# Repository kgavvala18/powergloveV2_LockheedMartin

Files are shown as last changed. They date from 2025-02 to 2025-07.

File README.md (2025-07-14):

# PowergloveV2 - Sponsored by Lockheed Martin

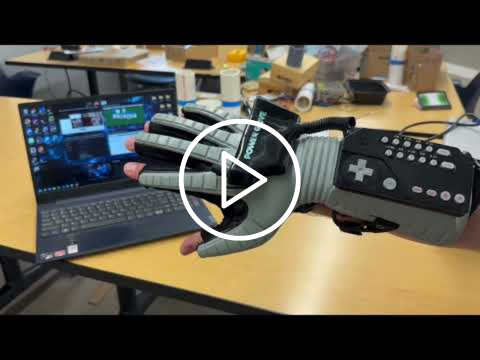
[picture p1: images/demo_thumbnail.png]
Watch the video (https://youtu.be/ArDcWYFsmJc)
||
|:--:|
| watch demo on youtube: https://www.youtube.com/watch?v=ArDcWYFsmJc|

The reimagined Power Glove enhances human-computer interaction by introducing a touchless interface that translates intuitive hand gestures into precise digital input. Designed to replace the traditional mouse, it enables seamless control through natural motion, offering a more ergonomic, immersive, and futuristic method of interaction. Users can simply connect the glove to their computer via Bluetooth and control it using hand movements. The glove tracks hand motion to move the cursor and detects gestures to trigger commands such as click, zoom, scroll, and more.

The system integrates an accelerometer/gyroscope IMU to track hand movement and orientation on three axes. Flex sensors embedded in each finger detect varying degrees of flexion, which, when combined with motion and orientation data, enable functions such as clicking, dragging, zooming, scrolling, and activating a laser pointer. Additional buttons on the glove provide quick access to common keyboard shortcuts like Ctrl+C and Ctrl+V. The Adafruit Feather nrf52840 Sense microcontroller was used for its processing speed, bluetooth LE, and usb charging capabilities.

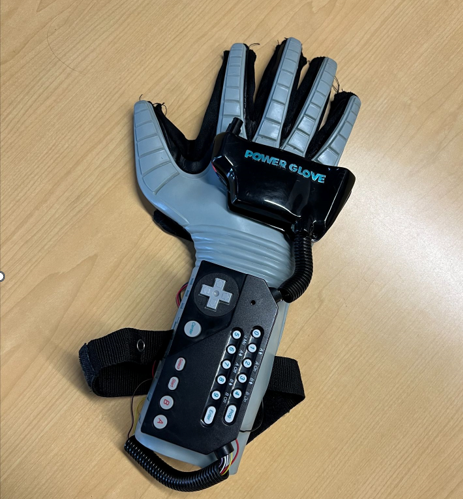
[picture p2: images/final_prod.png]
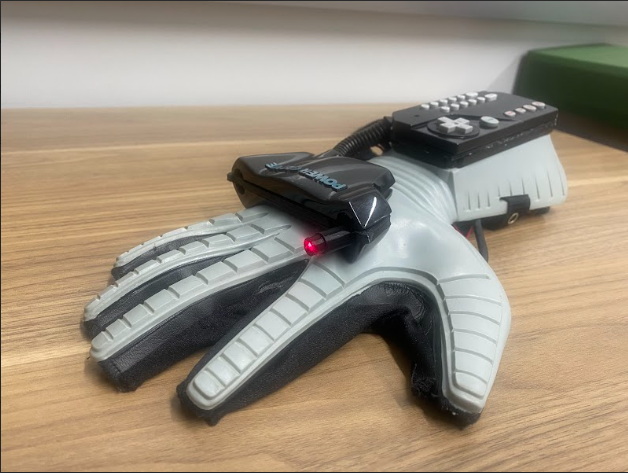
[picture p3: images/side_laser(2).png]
||
|:--:|:--:|

# Design 

Parts:

- [Adafruit feather nrf52840 sense](https://learn.adafruit.com/adafruit-feather-sense/overview)
- [LSMD6SOX IMU](https://learn.adafruit.com/lsm6dsox-and-ism330dhc-6-dof-imu/overview)
- 5x Flex sensors 
- Buttons 
- USB-C charging port
- Rechargeable 3.7 V LiPo battery
- 5x 400k ohm resistors
- 2n7000 mosfet transistor
- 10 uf capacitor
- 650 nm  5 mW laser

Layout: 

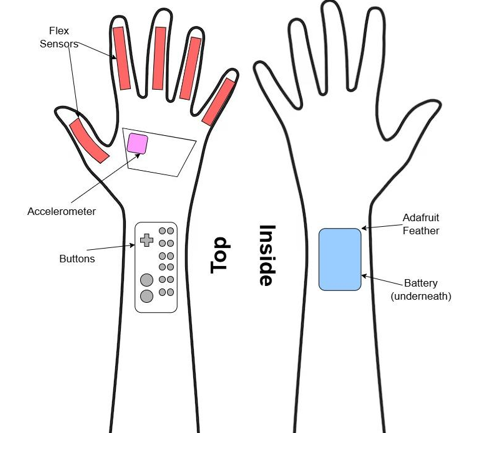
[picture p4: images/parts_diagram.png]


Level Diagram:

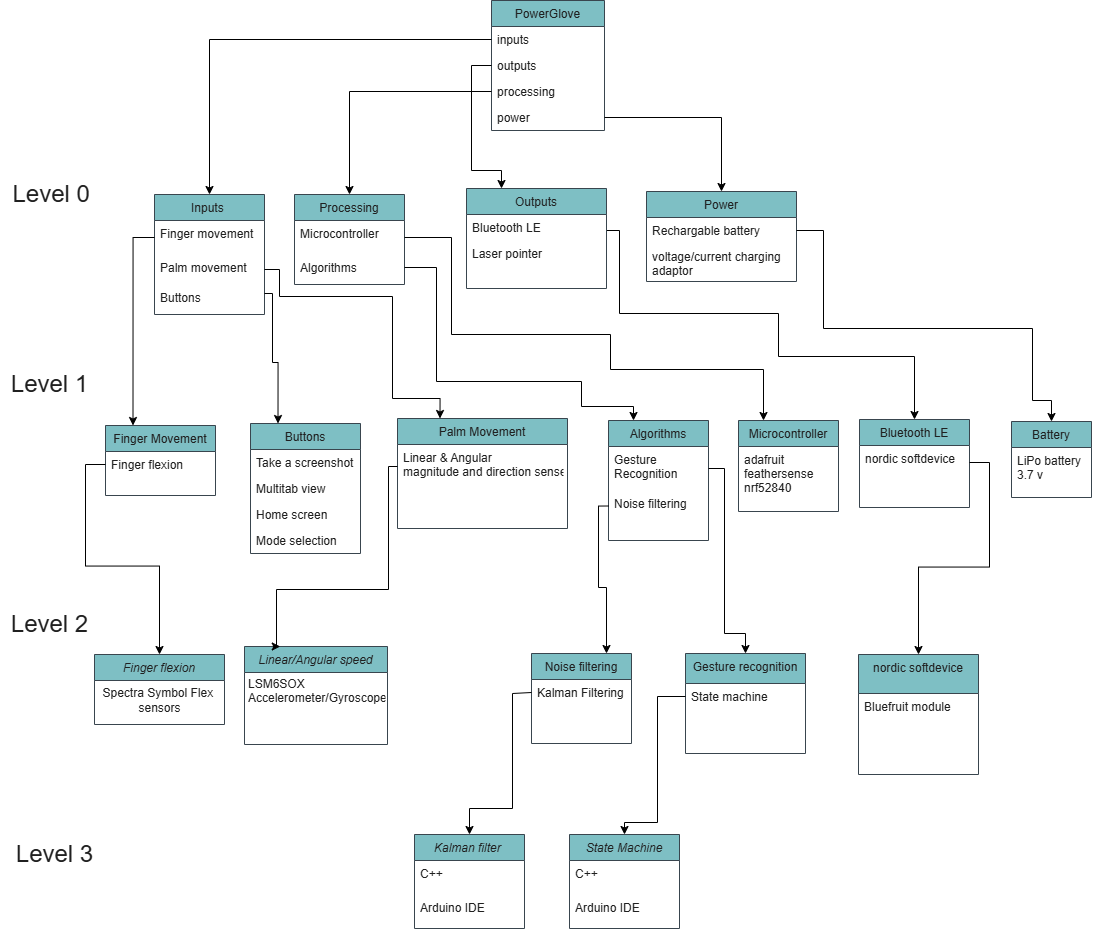
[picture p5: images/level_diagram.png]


# Project google drive folder
https://drive.google.com/drive/folders/1QBTlvf5KhOVl-Dzjxu-7hFhMazjApdm0?usp=sharing

# For Windows and Linux

1. Download Arduino IDE at https://www.arduino.cc/en/Main/Software
2. Start Arduino IDE and go to preference and add https://adafruit.github.io/arduino-board-index/package_adafruit_index.json as an 'Additional Board Manager URL'
3. Restart the IDE
4. Open Board Manager in the Tools -> Board and install 'Adafruit nRF52 by Adafruit'
5. After install use Tools -> Board to select Adafruit Feather nRF52840 Sense 

# For Windows Only

Windows Users will likely need to install the following two links
Select all options when installing below
https://learn.adafruit.com/adafruit-arduino-ide-setup/windows-driver-installation
CP210x Windows Drivers option is what I had to choose
https://www.silabs.com/developer-tools/usb-to-uart-bridge-vcp-drivers?tab=downloads

# For Linux Only 

Follow above windows steps and then follow below if python3 is not installed already

Linux Users will likely need to install https://www.silabs.com/developer-tools/usb-to-uart-bridge-vcp-drivers

1. Run `$ sudo apt-get install python3`
2. Run `$ pip3 install --user adafruit-nrfutil`
3. Add to path if needed
4. Ensure adafruit-nrfutil can be executed in terminal by running `$ adafruit-nrfutil version`

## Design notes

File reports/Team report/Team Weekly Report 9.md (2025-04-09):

**Team Weekly Report 9**

**Team:** The Gauntlet  
**Week:** 9  
**Members:** Kris Gavvala, [David Johnson](mailto:bluetech314@tamu.edu), [Aaron Martinez](mailto:aaron33@tamu.edu),  [Brint Nielson](mailto:brintcnielson@tamu.edu), [Will Tatum](mailto:willtaaa@tamu.edu), [Grant Turner](mailto:grantt731@tamu.edu)

| Status Report |
| :---- |

*Write a one-third to one-half page status report describing the team’s overall progress and challenges faced last week. Also discuss the team’s goals and plan for this week.*

The team has made good progress last week. The buttons have been assembled and the sensors have all been soldered in. The glove has now been mostly assembled with the main goal now being to make it pretty.
The team faced some challenged with fitting all of the sensors and wires within the enclosure and have been working on getting 3D printed pieces to remedy this.
The goals for this coming week are to finish assembling the glove and getting everything secured, finish integrating the gestures and buttons into the codebase, get the zoom functionality working, and if time permits, work on the drivers.

| Current Status |
| :---- |

1. What did the team work on this past week?

| Task | Task Lead | Status | Notes |
| :---- | :---- | :---- | :---- |
| Remade the buttons | Grant | Complete | No notes |
| Coding and assembly | Kris | Ongoing | Filtered flex sensors and assembled laser diode & glove |
| 3D printing | Brint | Ongoing | Need to test to develop and integrate |
| Bluetooth optimizations | Will | Complete | No notes |
| Soldering and assembly | Aaron | Ongoing | Got glove soldered with all of the sensors |
| Event code for buttons | David | Complete | Have not been able to test yet |

2. What feedback has the team received?

| From Whom | Feedback | Next Steps |
| :---- | :---- | :---- |
| Ritchey | Get predefined gestures working and assignable | Detect different gestures |
|  |  |  |

3. Are any resources needed? If so, what?

No

| Plans for Next Week |
| :---- |

What are your plans for this next week?

| Task | Task Lead | Notes |
| :---- | :---- | :---- |
| 3D Printing | Brint | Enclosure for laser and spacer |
| Integrate gestures and events into codebase | David | Will be done after testing |
| Drivers | Will | This is a stretch goal |
| Assembling the glove | Aaron | Continuation of glove assembly |
| Code the buttons | Grant | Build on event test code |
| Work on getting zoom working | Kris | Might be buttons or gesture |

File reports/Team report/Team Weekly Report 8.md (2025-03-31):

**Team Weekly Report 8**

**Team:** The Gauntlet  
**Week:** 8  
**Members:** Kris Gavvala, [David Johnson](mailto:bluetech314@tamu.edu), [Aaron Martinez](mailto:aaron33@tamu.edu),  [Brint Nielson](mailto:brintcnielson@tamu.edu), [Will Tatum](mailto:willtaaa@tamu.edu), [Grant Turner](mailto:grantt731@tamu.edu)

| Status Report |
| :---- |

*Write a one-third to one-half page status report describing the team’s overall progress and challenges faced last week. Also discuss the team’s goals and plan for this week.*

Last week, our group wrapped up all the individual components for the glove and it is partially assembled. We did have an issue with several members being ill which delayed our progress.   
The team will be finishing the glove’s assembly and will be moving on to getting the drivers. The next steps will be finishing the drivers, integrating them into the GUI, and getting all of the software and events onto the glove. We now have a prototype of the 3D printed spacer and will be getting a finalized version quickly.

| Current Status |
| :---- |

1. What did the team work on this past week?

| Task | Task Lead | Status | Notes |
| :---- | :---- | :---- | :---- |
| We set up the button encoder. | Grant | Complete |  |
| The Events are set up | David | Complete | Copy paste was dropped due to strange difficulties |
| Drivers | Brint | Ongoing | Need to test to develop and integrate |
| GUI | Will | Ongoing | Drivers are a prerequisite to ensuring GUI works |
| 3D print casings | Brint | Ongoing | Got good base prints down now need to adjust to fit the height as well |

2. What feedback has the team received?

| From Whom | Feedback | Next Steps |
| :---- | :---- | :---- |
|  |  |  |
|  |  |  |

3. Are any resources needed? If so, what?

Power switch.

| Plans for Next Week |
| :---- |

What are your plans for this next week?

| Task | Task Lead | Notes |
| :---- | :---- | :---- |
| Drivers | Brint |  |
| 3d Print  | Brint |  |
| GUI | Will |  |
| Assembling the glove | Aaron/Grant/Kris |  |
| Transferring events to glove | David |  |
| Finish flex sensors | Aaron/Grant/Kris |  |

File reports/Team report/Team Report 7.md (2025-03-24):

# Team Weekly Report

**Team**: The Gauntlet

**Week**: 7

**Members**: David, Grant, Brint, Kris, Aaron, Will

## Status Report

The team's overall progress is good. The glove is coming together swiftly and although we have had some setbacks from members being sick, progress has been good.
There has been work on hooking up the buttons to the encoders, getting everything soldered for the status demo, and some more mouse movement along with some gestures.
We have made progress on the 3D printing side but are having difficulties with the strange geometry of the parts we are trying to print for. The GUI has made progress
but now it needs some drivers to connect the keybinds to the glove and be able to light up a hand SVG properly. The drivers have been difficult to do because none of our
members have experience working on Windows drivers.

## Current Status
The glove is coming along very well and we have a working prototype. We are working on getting the housing, the buttons, the drivers, and the GUI to work.

### What did the team work on this past week?

| Task | Task Lead | Status | Notes |
| ---- | --- | --- | ----- |
| GUI | Will | In Progress | Needs the drivers to continue |
| Soldering | Aaron | Complete | Will need to be changed again |
| Buttons | Grant | In Progress | Hooked up to the encoders |
| Mouse Movement Code | Kris | In Progress | Need to experiment with deadzones |
| 3D Printing | Brint | In Progress | Hard to measure irregular surfaces accurately |
| Gestures | David | In Progress | Needs drivers to finish |

### What feedback has the team receieved?

| From Whom | Feedback | Next Steps |
| --- | --- | --- |
| Ritchey | Need clear demo (would like the GUI lightup thing) | Get the drivers working + SVG |
| Trevor | Try to ensure form factor with 3D printing | Keep our solutions minimally invasive to form factor |
| | | |

### Are any resources needed? If so, what?
We need a new charger piece and may need a new bluetooth module.

## Plans for Next Week

| Task | Task Lead | Notes |
| ---- | --- | ----- |
| Finish the buttons | Grant | They are hooked up to the encoders and are being put in the glove soon |
| Finish the cursor | Kris | Experimenting with deadzones and some other techniques |
| Finish the gestures | David | Gestures are coming along decently but need more precision |
| Finish the drivers | Will/Brint | Windows drivers are a new experience and are taking some time |
| Finish the 3D printing | Brint | 3D printing is facing some challenges with the geometry |
| Finish putting glove together | Aaron | Ordered more flex sensors since one of them is bending |

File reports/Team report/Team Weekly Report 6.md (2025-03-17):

**Team Weekly Report 6**

**Team:** The Gauntlet  
**Week:** 6  
**Members:** Kris Gavvala, [David Johnson](mailto:bluetech314@tamu.edu), [Aaron Martinez](mailto:aaron33@tamu.edu),  [Brint Nielson](mailto:brintcnielson@tamu.edu), [Will Tatum](mailto:willtaaa@tamu.edu), [Grant Turner](mailto:grantt731@tamu.edu)

| Status Report |
| :---- |

The overall progress is that the glove is nearing a functional prototype. The assembly work is underway and will be completed soon along with having some gestures set up. The GUI is also being developed and will be finished in time. The translation code and the button encoder were both completed and are ready for the next steps. The development environment for the drivers has been set up and the parts are being designed for 3D printing. The challenges faced last week included the error from the magnetometer. The team had to purchase a better one to reduce the errors after integrating it.  
Our goal for this week is to assemble the glove to have a prototype that we can test. We want to integrate all of the separate pieces onto the glove such as the flex sensors, controller, and buttons. While this occurs, some team members will continue software development, making drivers, the GUI, and new events.

| Current Status |
| :---- |

1. What did the team work on this past week?

| Task | Task Lead | Status | Notes |
| :---- | :---- | :---- | :---- |
| We set up the button encoder. | Grant | Complete |  |
| Translation code | Brint/Will | Complete | Sometimes loses track of the mouse, may incorporate a magnetometer for a reference |
| Drivers | Brint | Ongoing | Environment setup |
| GUI | Will | Ongoing | Technically started last weekend over spring break |

2. What feedback has the team received?

| From Whom | Feedback | Next Steps |
| :---- | :---- | :---- |
| Ritchey | Would like a GUI that lights up based on what you press | Work has started on this |
| Trevor | Would like the buttons to open apps | Thinking about how to incorporate this |

3. Are any resources needed? If so, what?

Polo Shirts?

| Plans for Next Week |
| :---- |

What are your plans for this next week?

| Task | Task Lead | Notes |
| :---- | :---- | :---- |
| Drivers | Brint |  |
| GUI | Will |  |
| Assembling the glove | Aaron/Grant/Kris |  |
| Developing more Events | David |  |
| Finish flex sensors | Aaron/Grant/Kris |  |

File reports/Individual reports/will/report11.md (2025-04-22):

# Individual Weekly Report

**Name**: Will Tatum

**Team**: The Gauntlet

**Date**: 04/21/2025

## Current Status
The glove is nearly done now and just needs to be touched up on the outside.

### What did _you_ work on this past week?

| Task | Status | Time Spent | 
| ---- | --- | --- |
| Gesture Detection | Complete | 8 hr |
| Report/Poster | Complete | 2 hr |
| | | |

*Include screenshots/diagrams/figures/etc. to illustrate what you did this past week.*
  previousGesture = currentGesture;
  currentGesture = gesture(thumbFiltered, indexFiltered, middleFiltered, ringFiltered, pinkyFiltered);
  Serial.println(currentGesture);

  switch (gestureState)
  {
  case IDLE:
    if (currentGesture == DRAG_GESTURE)
    {
      blehid.mouseButtonPress(MOUSE_BUTTON_LEFT);
      gestureState = DRAG_EVENT;
    }
### What problems did you run into? What is your plan for them?

We ran into problems with the glove's wires coming out. We have solved this issue.

### What is the current overall project status from your perspective? 

I would say that the project is about 99% done.

### How is your team functioning from your perspective?

The team is functioning well and we have minimal issues. We got a lot done this last week and are on track.

### What new ideas did you have or skills did you develop this week?

We figured out how to get the gesture detection working as well as we could with this hardware.

### Who was your most awesome team member this week and why?

Grant is my most awesome team member this week since he did all of the button code and got it working.

## Plans for Next Week

*What are you going to work on this week?*

I am going to work on the poster and report to help get it finalized along with some tests and user studies.

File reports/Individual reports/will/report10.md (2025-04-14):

# Individual Weekly Report

**Name**: Will Tatum

**Team**: The Gauntlet

**Date**: 04/14/2025

## Current Status
The glove is nearly done now and just needs a little more refinement on the gesture detection and the casing.

### What did _you_ work on this past week?

| Task | Status | Time Spent | 
| ---- | --- | --- |
| Gesture Detection | In Progress | 8hr |
| | | |
| | | |

*Include screenshots/diagrams/figures/etc. to illustrate what you did this past week.*
  // left mouse button
  switch (leftState)
  {
  case MOUSE_IDLE:
    // At idle, check if we have a new left-click or drag gesture.
    if (gesture_ == R) // should be I
    {
      // Initiate a discrete left-click event.
      // (According to our grammar, a click is I followed by NONE.)
      blehid.mouseButtonPress(MOUSE_BUTTON_LEFT);
      leftState = CLICK_EVENT;
      mouseEnabled = false;
    }

### What problems did you run into? What is your plan for them?

We ran into problems with the gesture detection having conflicts with itself. The plan is to basically wait until the new gesture has stabilized before switching to it.

### What is the current overall project status from your perspective? 

I would say that the project is about 90% done.

### How is your team functioning from your perspective?

The team is functioning well and we have minimal issues. We got a lot done this last week and are on track.

### What new ideas did you have or skills did you develop this week?

We had ideas on using the mean and stdev of the sensors to detect if they are stabilized or not. Another idea was a stabilization window for the gestures.

### Who was your most awesome team member this week and why?

Kris is my most awesome teammate this week because he spent a lot of time getting everything working.

## Plans for Next Week

*What are you going to work on this week?*

I am going to continue working on gesture detection.

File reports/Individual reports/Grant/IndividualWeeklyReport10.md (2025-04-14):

# Individual Weekly Report

**Name**: Grant Turner

**Team**: The Gauntlet

**Date**: 4/14/2025

## Current Status

### What did _you_ work on this past week?

| Task | Status | Time Spent |
| --- | --- | --- |
| Started adding the code for buttons | In progress | 5hr |

_Include screenshots/diagrams/figures/etc. to illustrate what you did this past week._

### What problems did you run into? What is your plan for them?

When I first wrote the code to check which button was being pressed, the matchButton function caused a lot of lag with the mouse movement due to running a nested loop every iteration. To fix this I added a check at the beginning of the function to check if the inputs match no button being pressed which greatly increased speed.

### What is the current overall project status from your perspective?

The project is about 85-90% done at this point. We have mostly every intended feature implemented just need to continue to refine them to improve usability.

### How is your team functioning from your perspective?

The team is still functioning pretty well and mostly everyone is pulling their weight.

### What new ideas did you have or skills did you develop this week?

I worked on writing more Arduino code and focused on writing optimized algorithms to avoid largely slowing down the main loop in our code.

### Who was your most awesome team member this week and why?

Will was the most awesome teammate as he easily fixed our issue with clicking while moving the mouse.

## Plans for Next Week

Completely finish the glove and get our presentations fully prepared.
_What are you going to work on this week?_
Finish the buttons completely and help with other code.

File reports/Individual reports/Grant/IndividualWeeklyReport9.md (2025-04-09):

# Individual Weekly Report

**Name**: Grant Turner

**Team**: The Gauntlet

**Date**: 3/31/2025

## Current Status

### What did _you_ work on this past week?

| Task | Status | Time Spent |
| --- | --- | --- |
| Install buttons into board | In Progress | 3hr |

_Include screenshots/diagrams/figures/etc. to illustrate what you did this past week._

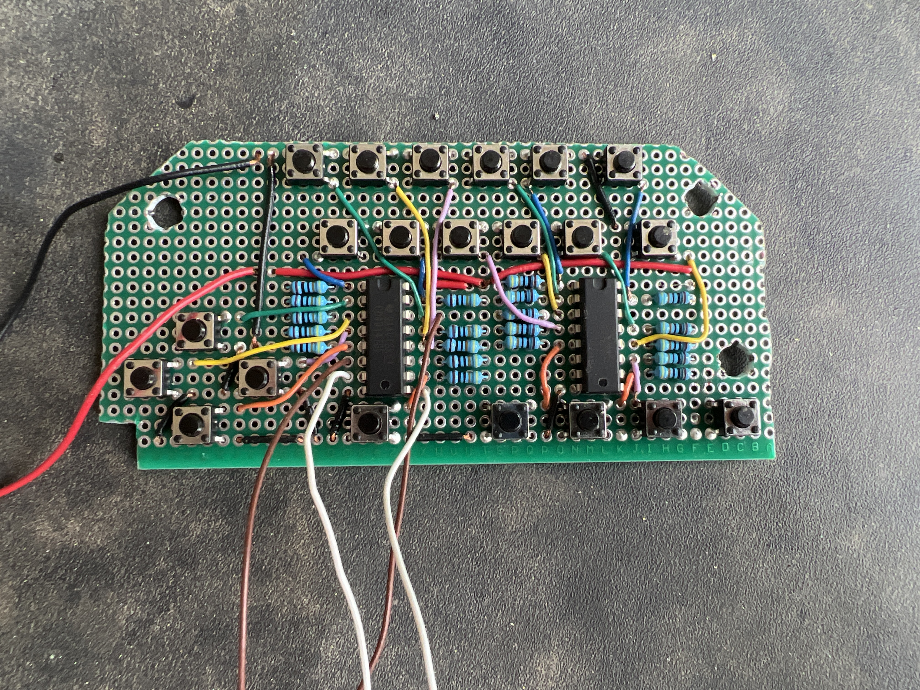
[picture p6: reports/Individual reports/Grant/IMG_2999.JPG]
New board with encoders and buttons wired together.


### What problems did you run into? What is your plan for them?

The old boards I built had issues with repeated outputs with different inputs. It was also just not put together very well and did not fit well in the housing.

### What is the current overall project status from your perspective?

We are about 85% complete at this point and have almost finished our working prototype, with all major components attached. We have been running into some issues now with adjusting tolerances and gettting click events to work well.

### How is your team functioning from your perspective?

The team is still functioning very well together and we have all worked well in getting all of our work done. There is nobody that has fallen behind or contributed too little.

### What new ideas did you have or skills did you develop this week?

I have continued soldering and building necessary circuitry.

### Who was your most awesome team member this week and why?

Kris was the most awesome teammate as he spent a ton of time tweaking the code and trying to get our protoype working good for the status demo and user studies.

## Plans for Next Week

Finish up the code for the buttons and help with mouse movement and finger based events.
_What are you going to work on this week?_
Finish up the gloves assembly and keep tweaking the code.

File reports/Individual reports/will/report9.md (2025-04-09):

# Individual Weekly Report

**Name**: Will Tatum

**Team**: The Gauntlet

**Date**: 03/31/2025

## Current Status
The glove is coming together very quickly and we now have a working prototype. I would say that the glove is 80% done. We do need to pick it up a bit though and will be on crunch time this week.

### What did _you_ work on this past week?

| Task | Status | Time Spent | 
| ---- | --- | --- |
| Report | In Progress | 30min |
| GUI | In Progress | 2hr |
| | | |

*Include screenshots/diagrams/figures/etc. to illustrate what you did this past week.*
Snippet of code to get the Bluetooth issues fixed.

void configBluetooth()
{
  // add any bluetooth config stuff here
  Bluefruit.configPrphBandwidth(BANDWIDTH_MAX);
  Bluefruit.configPrphConn(50, 8, 4, 4);
}

### What problems did you run into? What is your plan for them?

We ran into problems assembling the glove and solved them using 3D printing. The Bluetooth changes actually worked first try which was shocking so no problems there.

### What is the current overall project status from your perspective? 

I would say that the project is about 80% done. This is actually now true. Turns out I overestimated our completion.

### How is your team functioning from your perspective?

The team is functioning well and we have minimal issues. We got a lot done this last week and are on track.
### What new ideas did you have or skills did you develop this week?

No new ideas so far. A lot of catching up from before for us.

### Who was your most awesome team member this week and why?

Kris is my most awesome teammate this week because he spent a lot of time getting us good graphs of all the sensor data and filtering it.

## Plans for Next Week

*What are you going to work on this week?*

I am going to actually work on drivers this week since I ended up working on Bluetooth last week.

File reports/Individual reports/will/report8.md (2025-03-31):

# Individual Weekly Report

**Name**: Will Tatum

**Team**: The Gauntlet

**Date**: 03/31/2025

## Current Status
The glove is coming together very quickly and we now have a working prototype. I would say that the glove is 80% done. We do need to pick it up a bit though and will be on crunch time this week.

### What did _you_ work on this past week?

| Task | Status | Time Spent | 
| ---- | --- | --- |
| Report | In Progress | 30min |
| GUI | In Progress | 2hr |
| | | |

*Include screenshots/diagrams/figures/etc. to illustrate what you did this past week.*
Some HTML for the GUI
<head>
  <meta charset="UTF-8">
  <title>Glove Settings Menu</title>
  <style>
    body { font-family: sans-serif; margin: 20px; }
    .settings, .hand-display, .simulate { margin-bottom: 30px; }
    .sensor-input { margin: 10px 0; }
    .sensor-label { display: inline-block; width: 120px; }
    #handImage { width: 300px; }
    .sensor-btn { margin-right: 10px; margin-bottom: 5px; }
  </style>
</head>
### What problems did you run into? What is your plan for them?

Same problems as before. I ran into the issue of getting the hand to light up when a control is pressed. We need to get the drivers done and hooked up to it and get an SVG that we can light up portions of.

### What is the current overall project status from your perspective? 

I would say that the project is about 80% done. This has not really changed. Now that we are all done with exams, we are on crunch time.

### How is your team functioning from your perspective?

The team is functioning well and we have minimal issues. A lot of us have been getting sick and had a lot of exams in the last few weeks which has really set us back.

### What new ideas did you have or skills did you develop this week?

I had the idea to create a 3D model of the hand for the GUI menu. This could also be an SVG as before, currently investigating.

### Who was your most awesome team member this week and why?

Aaron was my most awesome team member of the week because he did a lot of work in soldering and helping to get the glove put together.

## Plans for Next Week

*What are you going to work on this week?*

I am going to work on getting the drivers working and the GUI connected to it for keybinds and stuff.

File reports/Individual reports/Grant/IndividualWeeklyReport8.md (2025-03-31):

# Individual Weekly Report

**Name**: Grant Turner

**Team**: The Gauntlet

**Date**: 3/31/2025

## Current Status

### What did _you_ work on this past week?

| Task | Status | Time Spent |
| --- | --- | --- |
| Install buttons into board | In Progress | 3hr |

_Include screenshots/diagrams/figures/etc. to illustrate what you did this past week._

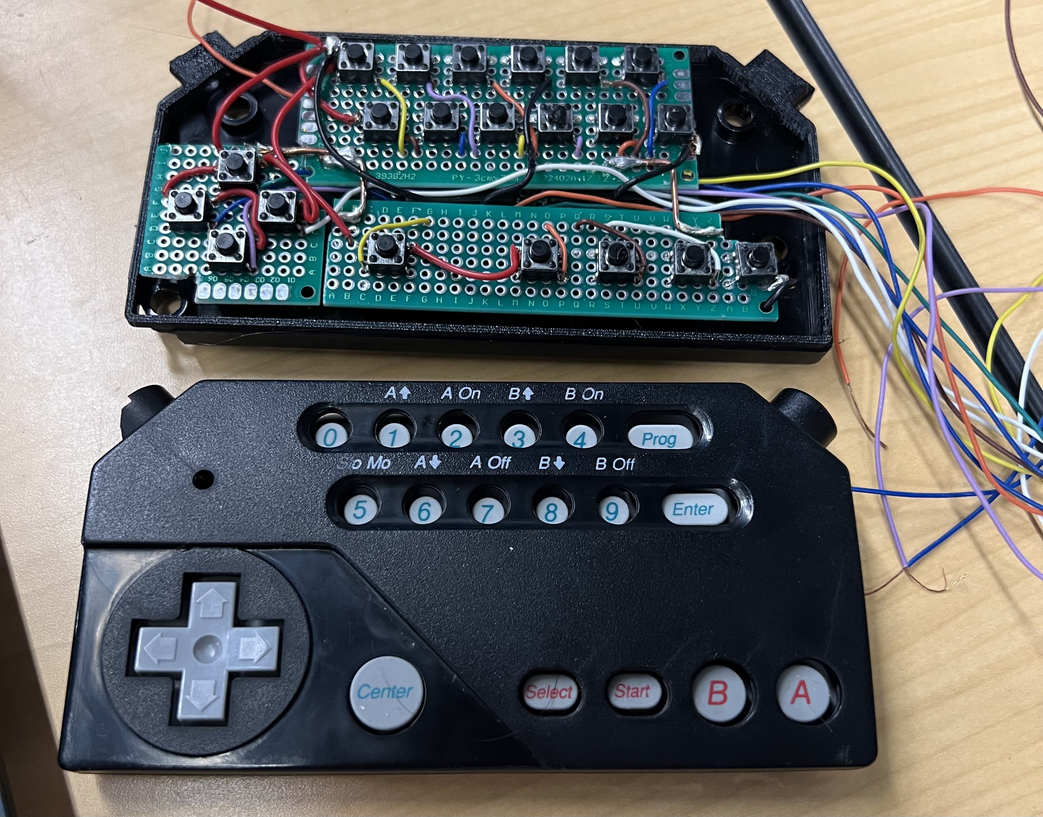
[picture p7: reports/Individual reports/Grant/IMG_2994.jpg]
Boards with encoders and buttons wired together.


### What problems did you run into? What is your plan for them?

I had an issue with some buttons giving the same output but I think it has been fixed.

### What is the current overall project status from your perspective?

We are about 80% complete at this point and have almost finished our working prototype, with all major components attached.

### How is your team functioning from your perspective?

The team is still functioning very well together and we have all worked well in getting all of our work done. There is nobody that has fallen behind or contributed too little.

### What new ideas did you have or skills did you develop this week?

I have continued soldering and building necessary circuitry.

### Who was your most awesome team member this week and why?

Brint was the most awesome teammate as he worked a lot on the drivers as well as 3D printing parts we need.

## Plans for Next Week

Get the code written for the button events as well as look into making the circuit board for the buttons more compact.
_What are you going to work on this week?_
Polishing the prototype and button press events.

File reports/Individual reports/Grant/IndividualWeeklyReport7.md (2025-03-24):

# Individual Weekly Report

**Name**: Grant Turner

**Team**: The Gauntlet

**Date**: 3/24/2025

## Current Status

### What did _you_ work on this past week?

| Task | Status | Time Spent |
| --- | --- | --- |
| Connect buttons to encoders | In Progress | 5hr |

_Include screenshots/diagrams/figures/etc. to illustrate what you did this past week._

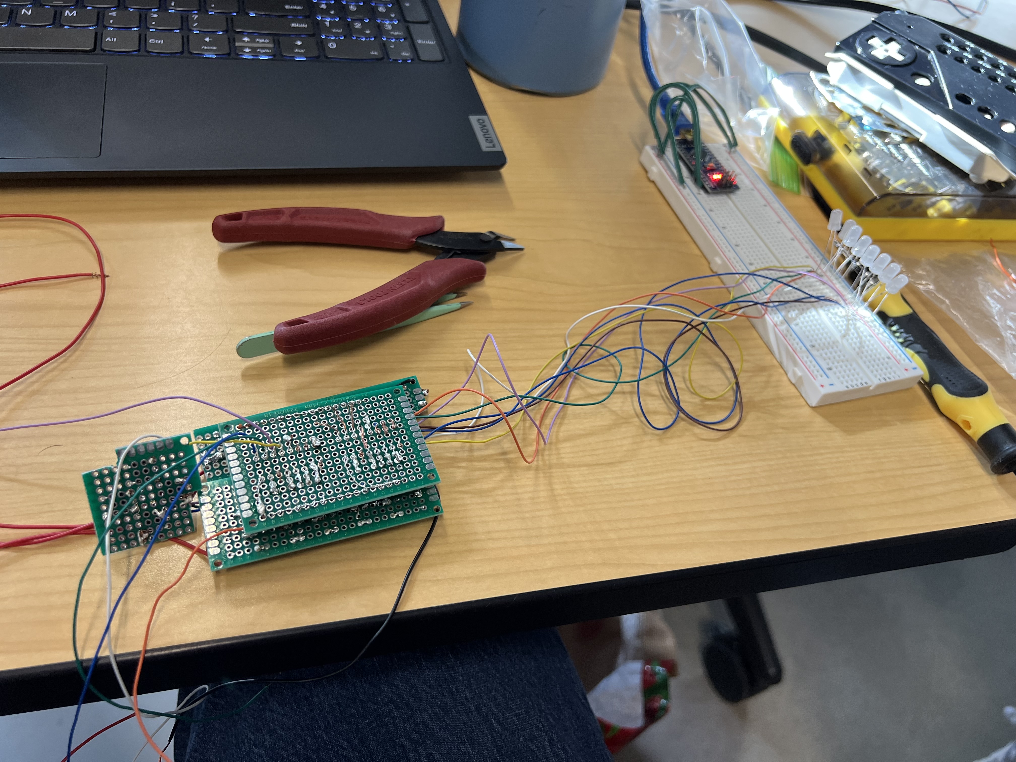
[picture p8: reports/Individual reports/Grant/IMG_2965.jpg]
Boards with encoders and buttons wired together.


### What problems did you run into? What is your plan for them?

The only problem I have encountered is dealing with soldering and connecting very small wires while avoiding shorts.

### What is the current overall project status from your perspective?

We are about 75% complete at this point and have created a working prototype, although very rough. The buttons will soon be ready to attach to the rest of the glove.

### How is your team functioning from your perspective?

The team is still functioning very well together and we have all worked well in getting all of our work done. There is nobody that has fallen behind or contributed too little.

### What new ideas did you have or skills did you develop this week?

I have practiced building circuits and learned about pull-up and pull-down resistor configurations.

### Who was your most awesome team member this week and why?

Kris was the most awesome teammate as he spent a lot of time getting the prototype working and polishing out the mouse movement with the new accelerometer, which much improved the smoothness of the mouse control.

## Plans for Next Week

Completely finish the buttons and get them wired to the microcontroller. Then I can begin writing code for the shortcuts the buttons will use.
_What are you going to work on this week?_
Adding the buttons to the prototype and getting the code setup to handle button presses.

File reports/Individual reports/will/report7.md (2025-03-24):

# Individual Weekly Report

**Name**: Will Tatum

**Team**: The Gauntlet

**Date**: 03/24/2025

## Current Status
The glove is coming together very quickly and we now have a working prototype. I would say that the glove is 80% done.

### What did _you_ work on this past week?

| Task | Status | Time Spent | 
| ---- | --- | --- |
| Report | In Progress | 10min |
| GUI | In Progress | 5hr |
| | | |

*Include screenshots/diagrams/figures/etc. to illustrate what you did this past week.*
Some HTML for the GUI
<head>
  <meta charset="UTF-8">
  <title>Glove Settings Menu</title>
  <style>
    body { font-family: sans-serif; margin: 20px; }
    .settings, .hand-display, .simulate { margin-bottom: 30px; }
    .sensor-input { margin: 10px 0; }
    .sensor-label { display: inline-block; width: 120px; }
    #handImage { width: 300px; }
    .sensor-btn { margin-right: 10px; margin-bottom: 5px; }
  </style>
</head>
### What problems did you run into? What is your plan for them?

I ran into the issue of getting the hand to light up when a control is pressed. We need to get the drivers done and hooked up to it and get an SVG that we can light up portions of.

### What is the current overall project status from your perspective? 

I would say that the project is about 80% done. It is coming along pretty fast and as more of us finish up midterms it is going to accelerate a lot.

### How is your team functioning from your perspective?

The team is functioning well and we have minimal issues. A lot of us have been getting sick in the last few weeks which has really set us back.

### What new ideas did you have or skills did you develop this week?

I did not have any new ideas except for maybe the SVG for the hand. I developed skills using electron js.

### Who was your most awesome team member this week and why?

Brint was my most awesome team member this week because he did 3D printed the glove spacer and is working on getting it working well.

## Plans for Next Week

*What are you going to work on this week?*

I am going to work on getting the drivers working and the GUI connected to it for keybinds and stuff.

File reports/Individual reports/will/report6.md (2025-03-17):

# Individual Weekly Report

**Name**: Will Tatum

**Team**: The Gauntlet

**Date**: 03/17/2025

## Current Status
The glove is nearing a functional prototype and is being assembled. The code is mostly done for movement but we are adding gestures and getting some driver code done along with a GUI.

### What did _you_ work on this past week?

| Task | Status | Time Spent | 
| ---- | --- | --- |
| Translation Movement Code | Complete | 5hr |
| GUI | Ongoing | 2hr |
| | | |

*Include screenshots/diagrams/figures/etc. to illustrate what you did this past week.*
const createWindow = () => {
  // Create the browser window.
  const mainWindow = new BrowserWindow({
    width: 800,
    height: 600,
    webPreferences: {
      preload: path.join(__dirname, 'preload.js')
    }
  })

### What problems did you run into? What is your plan for them?
The accelerometer was not good enough for the code. We have gotten a better separate one.

### What is the current overall project status from your perspective? 
70% since we need to assemble the glove and finish up some code.

### How is your team functioning from your perspective?
The team is functioning well. No issues so far.

### What new ideas did you have or skills did you develop this week?
Translation code used Kalman filters and other methods to try and reduce errors.

### Who was your most awesome team member this week and why?
Aaron because he got the flex sensors in the glove.

## Plans for Next Week
Work on the GUI.
*What are you going to work on this week?*

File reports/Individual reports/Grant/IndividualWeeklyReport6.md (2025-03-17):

# Individual Weekly Report

**Name**: Grant Turner

**Team**: The Gauntlet

**Date**: 3/17/2025

## Current Status

### What did _you_ work on this past week?

| Task | Status | Time Spent |
| --- | --- | --- |
| Tested encoder chips to verify functionality | Complete | 2hr |
| Planned out how to wire encoder to buttons | Complete | 1hr |

_Include screenshots/diagrams/figures/etc. to illustrate what you did this past week._

None

### What problems did you run into? What is your plan for them?

I had a small issue with the encoders. I did not realize that the data sheet had very small in paratheses that the inverse logic was used, so all 0's were 1's and all 1's were 0's. The encoder is still usable but I had to slightly change how the circuity was wired.

### What is the current overall project status from your perspective?

The project is still moving along well and we are getting prepared to put the new components into the glove itself. This will likely be the more difficult than previous tasks as we will need to 3D parts to increase the space in the button and microcontroller housings on the glove.

### How is your team functioning from your perspective?

The team is still working well and we have been making steady progress still.

### What new ideas did you have or skills did you develop this week?

I had some ideas on what to do with some of the buttons like opening commonly used applications. This may involve mapping buttons to different keyboard inputs like ctrl+shift+1, which the user will need to set up in their OS to open the app of their choice.

### Who was your most awesome team member this week and why?

Kris was the most awesome teammate as he bought a new accelerometer and wrote some code to make the mouse movement work with translation rather than just being tilt based.

## Plans for Next Week

Wire encoder to the actual buttons and place all the pcb boards inside the button housing. Start creating buttons press events to perform tasks on users machine.
_What are you going to work on this week?_
Begin actual glove assembly to create a functional protoype for further testing and devoplment.

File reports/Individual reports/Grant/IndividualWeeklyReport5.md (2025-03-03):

# Individual Weekly Report

**Name**: Grant Turner

**Team**: The Gauntlet

**Date**: 3/3/2025

## Current Status

### What did _you_ work on this past week?

| Task | Status | Time Spent |
| --- | --- | --- |
| Built circuit board for buttons | Complete | 5hr |
| Created simple Arduino based encoder for testing | Complete | 20min |

_Include screenshots/diagrams/figures/etc. to illustrate what you did this past week._

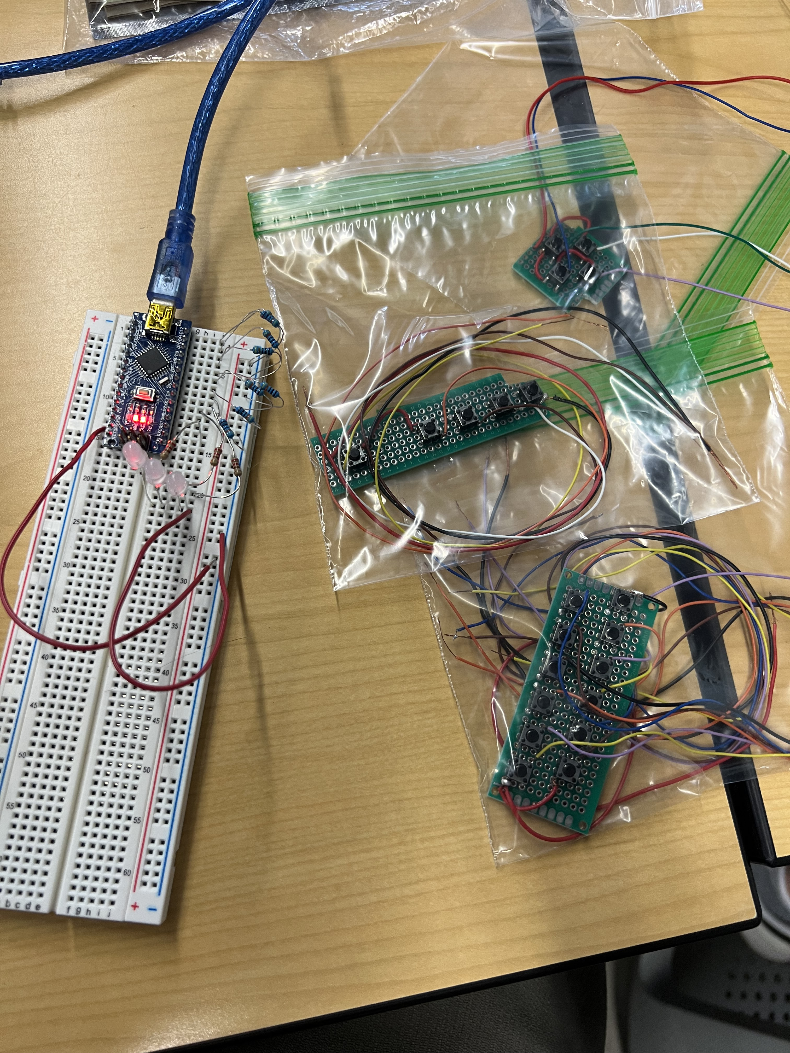
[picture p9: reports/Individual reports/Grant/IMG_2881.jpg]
Buttons and Arduino Test Circuit


### What problems did you run into? What is your plan for them?

I ran into an issue with the encoders we have as they require all inputs below the highest signigance input to be high to work properly. This does not work well with the way we want the buttons to work unless we add a large amount of circuitry.

### What is the current overall project status from your perspective?

I think we are over halfway done with the project in total, but the hardest parts will be coming up. Creating our own driver and implementing the more complicated functionality could prove to be more difficult than anything we have done so far.

### How is your team functioning from your perspective?

The team is still functioning very well together and we have all worked well in getting all of our work done. There is nobody that has fallen behind or contributed too little.

### What new ideas did you have or skills did you develop this week?

I have practiced in writing Arduino code and soldered even more things, which were very small.

### Who was your most awesome team member this week and why?

Brint was the most awesome teammate this week due to his work he did at home including researching and setting up basic driver development.

## Plans for Next Week

This week I will do more research on encoders so I can purchase some that work well for our intended goals. I will also begin writing code for the buttons on our actual microcontroller so that they have actual functionality.
_What are you going to work on this week?_
I will purchase the correct encoders and wire the buttons to them and begin to create functionality for each button.

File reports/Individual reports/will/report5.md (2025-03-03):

# Individual Weekly Report

**Name**: Will Tatum

**Team**: The Gauntlet

**Date**: 03/03/2025

## Current Status
The current status of the project is that we are making good progress on both the hardware and software and are over halfway done.

### What did _you_ work on this past week?

| Task | Status | Time Spent | 
| ---- | --- | --- |
| Translation Movement | In Progress | 4 hrs |
| Keyboard Controls Research | Complete | 3 hrs |
| Fixing Gesture Sensor Code | Complete | 1 hr |

*Include screenshots/diagrams/figures/etc. to illustrate what you did this past week.*
Small code snippet from the translation movement code which is basically what we already have with some additions.

unsigned long currentTime = millis();
  float dt = (currentTime - lastTime) / 1000.0;
  lastTime = currentTime;

  // Update velocity by integrating acceleration.
  // Mapping: horizontal movement from accel_y and vertical movement from -accel_x
  vel_x += accel_y * dt;
  vel_y += -accel_x * dt;

  // Apply damping to reduce drift
  vel_x *= 0.9;
  vel_y *= 0.9;

  // Scale the integrated velocity to determine mouse movement.
  // (You can tune the scale factor below as needed.)
  int mouse_dx = (int)(vel_x * 10);
  int mouse_dy = (int)(vel_y * 10);

  // Move the mouse accordingly
  blehid.mouseMove(mouse_dx, mouse_dy);
### What problems did you run into? What is your plan for them?

We ran into issues with finding the left control key. The plan is to try detecting it as a modifier rather than a key.

### What is the current overall project status from your perspective? 

I would say it is about halfway to a bit over halfway done.

### How is your team functioning from your perspective?

The team is functioning well.

### What new ideas did you have or skills did you develop this week?

I developed skills on trying to get the board to detect translational movement for moving the mouse.

### Who was your most awesome team member this week and why?

Grant was my most awesome team member. He got the buttons to function with a test circuit.

## Plans for Next Week

The plan for next week is to refine our mouse movement and get gestures working.

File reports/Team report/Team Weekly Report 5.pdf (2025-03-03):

### Team Weekly Report

Team: The Gauntlet
Week: 5
Members: Kris Gavvala, David Johnson , Aaron Martinez , Brint Nielson , Will Tatum , Grant Turner

Status Report

### The team has made good progress on integrating the new hardware with the software. As of

now, the glove can both left and right click. The new flex sensors have been added and put into

### the glove. There has been progress on getting screen zoom to work along with getting the

buttons on the glove to be functional. The challenges last week came from trying to get the left control key to work as it would increase the volume rather than press left control. This was hopefully overcome and will be part of the next report. The team is also working on a different type of mouse movement along with getting mouse scrolling to work. The goals for this week are to try and finish scrolling and the new movement method to get ready for user testing. The current plan for the glove is to now solder the flex sensors and other sensors along with gluing the glove’s fabric closed once everything is ready.

Current Status
1. What did the team work on this past week?
Task | Task Lead | Status | Notes
Built button pads | Grant | Complete
Built Arduino based encoder | Grant | Complete | Can possibly add more inputs and outputs
Soldering and inputting flex sensors in glove | Aaron | In progress | Have 2 more flex sensors to add
Ctrl modifiers for input | David | Complete
Mouse integration movement refinement | Brint | In progress | Need to overcome a lot of sensor noise
Driver Development | Brint | In progress
Mouse movement using translation | Will | In progress | Same issue as Brint with the mouse integration movement
Zoom Gesture | David | In progress | Need to convert from keyboard event to glove event

2. What feedback has the team received?
From Whom | Feedback | Next Steps
Ritchey | Get a functional prototype for a live demo | Get everything sealed
Ritchey | Keep up to date on jira | Ensure we manage our Jira tasks
3. Are any resources needed? If so, what?
So far everything we could see us needing we have ordered for ourselves.

Plans for Next Week
What are your plans for this next week?
Task | Task Lead | Notes
Incorporate actual encoders to save space for buttons | Grant
Finish adding flex sensors | Aaron
Add functions and determine thresholds for fingers | Aaron
Continue driver development | Brint
Continue making mouse integration movement work | Brint
Mouse movement using translation continuation | Will
Convert events on keyboard to glove events | David | This includes zoom and mouse disablement

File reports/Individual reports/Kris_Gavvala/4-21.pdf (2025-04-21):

### Individual Weekly Report

Name: Kris Gavvala
Team: Powerglove
Date: 4/21/2025

Current Status
1. What did you personally work on this past week?
Task | Status | Time Spent
Helped refine gesture detection | done | 5 hrs
Reworked some hardware on glove | done | 2 hrs

Include screenshots/graphics to illustrate what you did this past week:

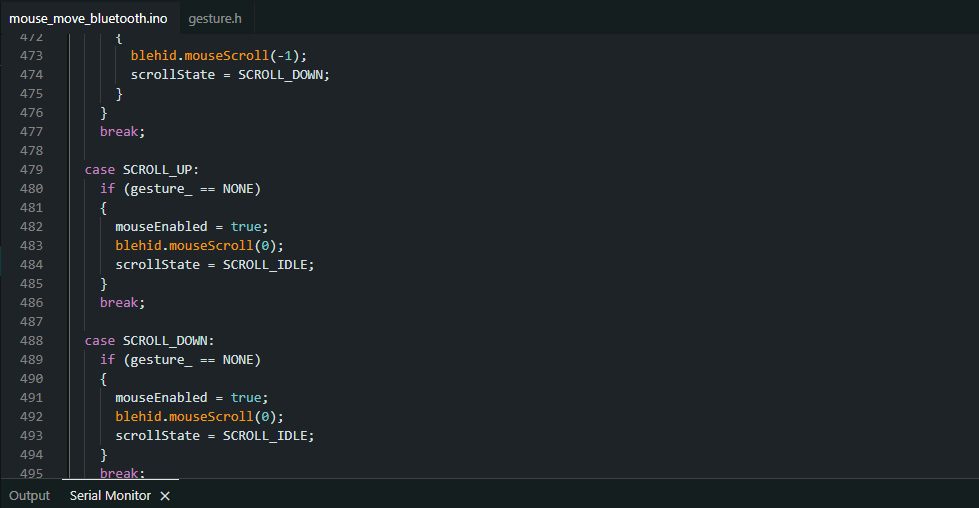
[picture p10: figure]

Figure 1: I helped Will refine the gesture-sensing code

2. What problems did you run into? What is your plan for them?
Needed to find a good average threshold for finger flexion since not all people do it the same so we had to find a good average value for each finger threshold and test with every gesture

3. What is the current overall project status from your perspective?
a. We are just finished with the glove. Need to work on presentation and make the poster look a lot better.
4. How is your team functioning from your perspective?
a. Everyone on this team works well together and prioritizes team goals above any personal issues except for one member who is unfortunately our team lead. During these last couple weeks, everyone but him was willing to meet up outside class time and do whatever it took to wrap up product development. However, the only thing David did was constantly ask when everything was going to be finished, instead of how he could help with the remaining work. Since David had not done much work building the project and we were busy getting it ready for the expo, we trusted him to make the poster presentation, but we were disappointed with the result. As team lead, David also has not done anything to manage roles and tasks which definitely handicapped our efforts. He never even looked at the Jira page( Brint does all the Jira updates). I didn’t say anything since I wanted to give him a chance to improve, but his refusal to change really stood out this last week. Other than him, everyone else is a great teammate and that’s why we were able to finish the project in time.
5. What new ideas did you have or skills did you develop this week?
a. I had some ideas to change the poster to make it pop a little more. I also might want to edit the zoom feature to use fingers instead.
6. Who was your most awesome team member this week and why?
a. Grant and Will. Grant is a highly dependable teammate and did great work with the hardware and software of all the button logic. If he is assigned a task he always finds a way to get it done with high quality. Will put a lot of effort into the gesture code, which was one of the more complicated parts of the project.

Plans for Next Week
What are you going to work on this next week?

Work on the presentation. Edit the poster.

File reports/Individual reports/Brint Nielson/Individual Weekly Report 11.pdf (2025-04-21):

### Individual Weekly Report

Name: Brint Nielson
Team: The Gauntlet
Date: 4/21/2025

Current Status
1. What did you personally work on this past week?
Task | Status | Time Spent
Make new stl files for new needs and test prints | In progress | 8 Hour
Start a different approach to help code refining | In progress | 30 mins

Include screenshots/graphics to illustrate what you did this past week:

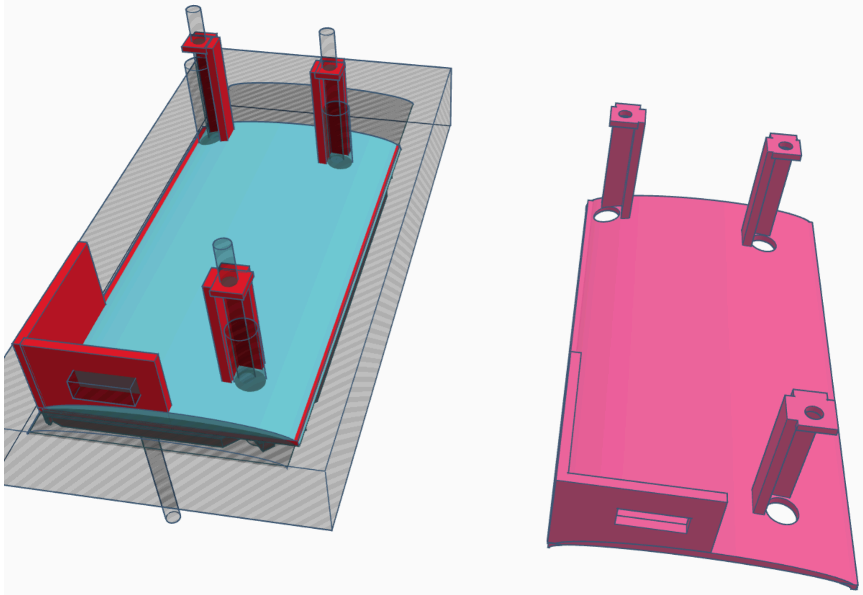
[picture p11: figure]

2. What problems did you run into? What is your plan for them?
Just was a bit busy but I was able to plan around it to get decent work in with the team still.
3. What is the current overall project status from your perspective?
We are essentially done it is now just refining and improving code while also making it look pretty.
4. How is your team functioning from your perspective?
Great we have pretty much finished up now just work on presentations and finalizations.
5. What new ideas did you have or skills did you develop this week?
Got a way better idea of how to actually print nice looking 3d prints and design them as well. And new ideas of how to potentially improve the code.
6. Who was your most awesome team member this week and why?
I would put Kris and Will since they put in a lot of work in their free time to improve more upon the code.

Plans for Next Week
What are you going to work on this next week?
Improve code finalizations and performance and final prints for 3d prints.

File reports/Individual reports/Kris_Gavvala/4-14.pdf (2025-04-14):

### Individual Weekly Report

Name: Kris Gavvala
Team: Powerglove
Date: 4/14/2025

Current Status
1. What did you personally work on this past week?
Task | Status | Time Spent
Helped code gestures detection | done | 5 hrs
Added accelerometer readings to track motion | done | 2 hrs

Include screenshots/graphics to illustrate what you did this past week:


Figure 1: I helped Will create the gesture-sensing code

2. What problems did you run into? What is your plan for them?
We had some trouble differentiating gestures since a lot of the finger movements can overlap with each other and trigger unwanted actions. We were able to solve this by refining some of the grammar in the switch statements.

3. What is the current overall project status from your perspective?
a. We are just about finished. Just need to put the finishing touches on the glove to make it look nice.
4. How is your team functioning from your perspective?
a. Pretty well. We have been collaborating very well in recent weeks to get a lot of stuff done.
5. What new ideas did you have or skills did you develop this week?
a. Learned some more about sensor fusion.
6. Who was your most awesome team member this week and why?
a. Grant and Will. Grant did a good job finishing the buttons and the code for it. Will was especially helpful and did a lot of work with the gesture code. The gestures would not be working if not for Will’s efforts.

Plans for Next Week
What are you going to work on this next week?

Work on the presentation. Put the final touches to improve how the glove looks. Do some more user studies and see if there are minor usability issues to improve.

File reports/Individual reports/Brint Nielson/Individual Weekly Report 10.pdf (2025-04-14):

### Individual Weekly Report

Name: Brint Nielson
Team: The Gauntlet
Date: 4/14/2025

Current Status
1. What did you personally work on this past week?
Task | Status | Time Spent
Make new stl files for new needs and test prints | In progress | 7 Hour

Include screenshots/graphics to illustrate what you did this past week:

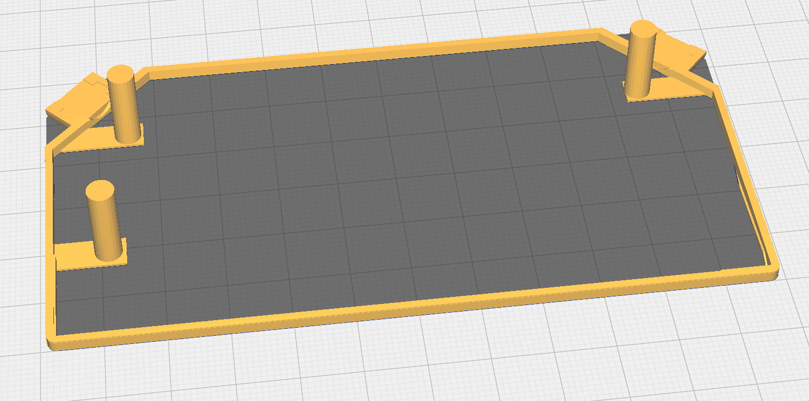
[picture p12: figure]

2. What problems did you run into? What is your plan for them?
Did not work on drivers this week as I think we have refined the glove without drivers enough to be good without the need for drivers, and instead drivers would be way too much work for this late in the semester.
3. What is the current overall project status from your perspective?
Further refining and testing and then prettying it up.

4. How is your team functioning from your perspective?
Great we are close to finalizing and working on problems we have had.
5. What new ideas did you have or skills did you develop this week?
Learned how bad drivers are and got more of an idea of how to 3d print the final things we need when our hardware is ready for it.
6. Who was your most awesome team member this week and why?
I would put Kris and Will since they put in a lot of work over the weekend to get code refined.

Plans for Next Week
What are you going to work on this next week?
Finish up 3d prints and put them in and help with finalizing code.

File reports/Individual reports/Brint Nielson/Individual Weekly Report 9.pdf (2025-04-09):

### Individual Weekly Report

Name: Brint Nielson
Team: The Gauntlet
Date: 4/7/2025

Current Status
1. What did you personally work on this past week?
Task | Status | Time Spent
Develop and test drivers | In progress | 4 Hour
Adjust STL files for print casing and print casing | Complete for most just need final measurements after device testing | 5.5 hour

Include screenshots/graphics to illustrate what you did this past week:

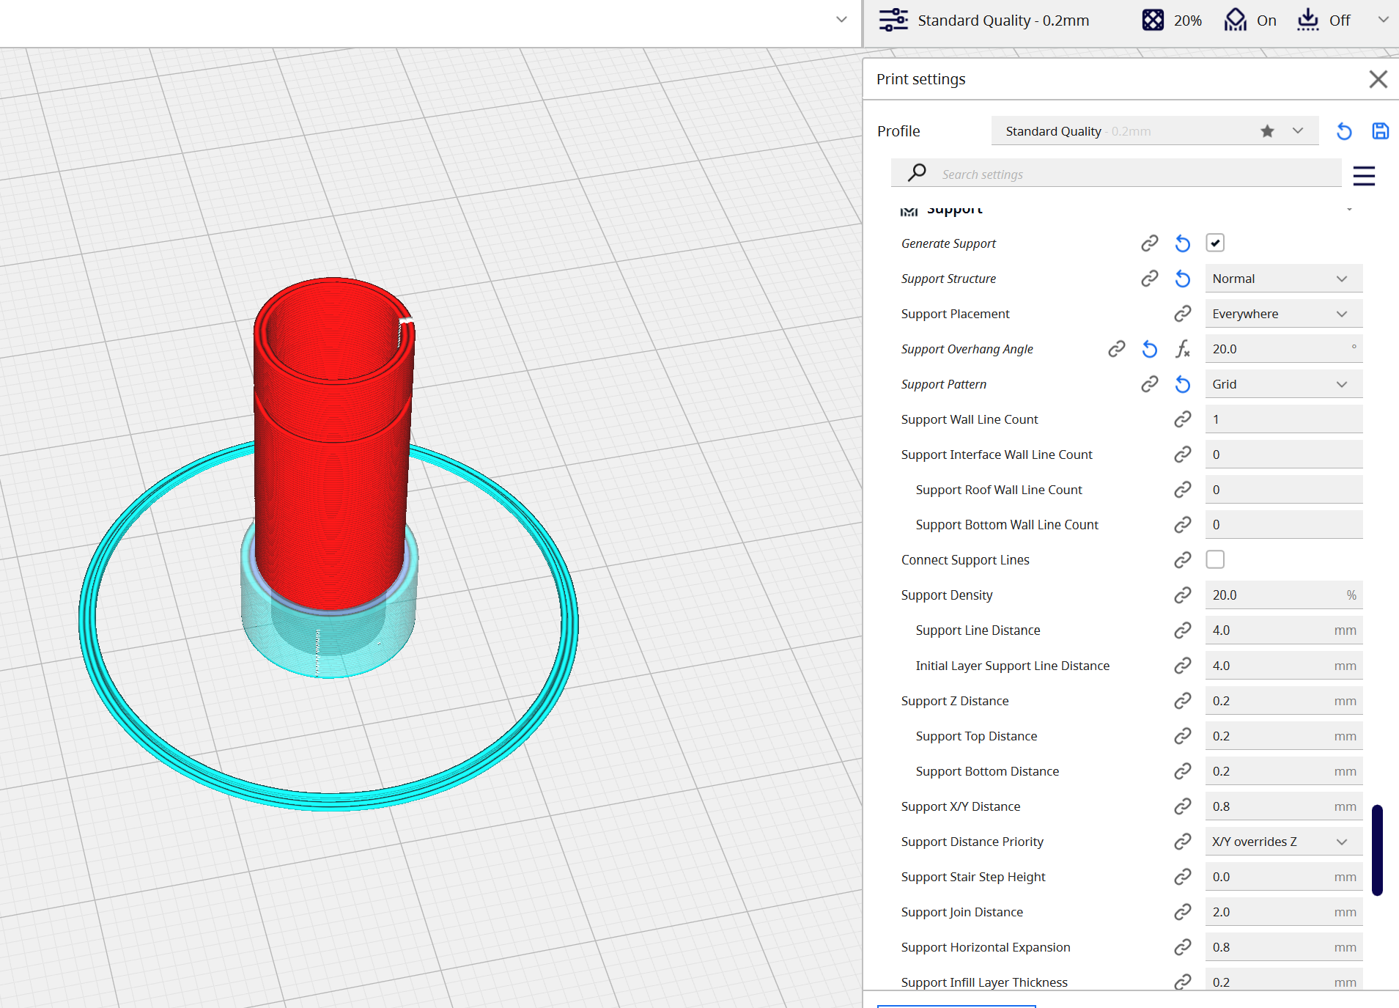
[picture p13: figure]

2. What problems did you run into? What is your plan for them?
Even though drivers are a stretch goal we wanted to get them done before this week but we ran into the problem of non stretch goals had to take priority and we weren't able to test the drivers like we needed.
3. What is the current overall project status from your perspective?
Finalizing putting together and then working on prettying it up.
4. How is your team functioning from your perspective?
Great we have the ability to test and will keep refining it and making it look prettier.
5. What new ideas did you have or skills did you develop this week?
Learning just how hard drivers are to understand for Arduino and how annoying Bluetooth LE can be. Also learned more how to 3d print stuff.
6. Who was your most awesome team member this week and why?
I would put Kris, Aaron, and Grant as the most awesome as they were on the hardware side and put in a lot of work this past week to get it together.

Plans for Next Week
What are you going to work on this next week?
First making sure the glove works well and prettying it up and then stretch goals as well.

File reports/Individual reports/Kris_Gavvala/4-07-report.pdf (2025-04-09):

### Individual Weekly Report

Name: Kris Gavvala
Team: Powerglove
Date: 4/7/2025

Current Status
1. What did you personally work on this past week?
Task | Status | Time Spent
Helped build final hardware prototype | done | 5 hrs
Helped incorporate bluetooth communication with current mouse movement code. | done | 2 hrs

Include screenshots/graphics to illustrate what you did this past week:

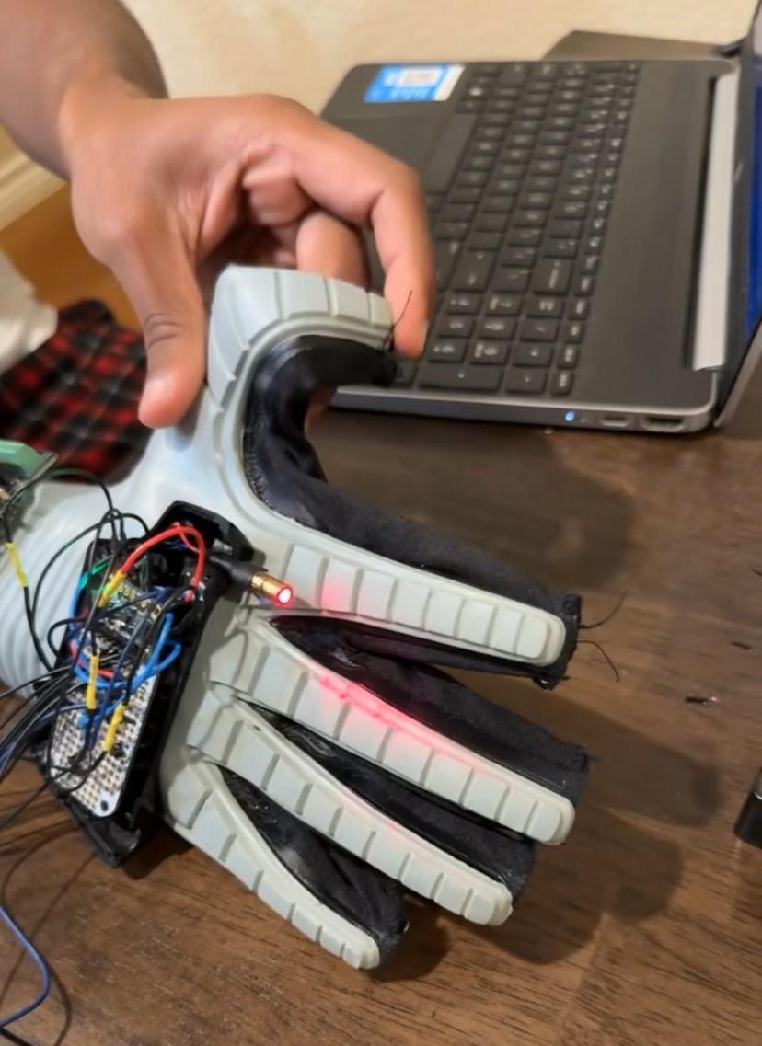
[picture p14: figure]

Figure 1: I helped Aaron solder our accelerometer and flex sensors to the proto-board and created the circuit for the laser pointer. We had to consider space restrictions of our board housing to make everything fit

2. What problems did you run into? What is your plan for them?
a. For mouse movement and clicking, there needs to be a better way to differentiate which flex sensor is being activated. Some users in our studies have a natural hand position where they bend their fingers more, and this activates sensors when they shouldn’t. We need to detect a finger gesture based on the difference between one flex sensor and other flex sensors
b. Users have said that the glove is not a very intuitive way to interface with a computer. Even though moving the accelerometer to the hand improved mouse stability while clicking, it is still hard to click very tiny objects because of the natural instability of the hand. To solve this, we need to sense when a click might be coming so the mouse becomes more stable during that small time frame. (right now we are using angular velocity to move the mouse, but we might try using acceleration values to detect the dead zone).
c. To improve usability we will also fuse the linear accelerometer values
3. What is the current overall project status from your perspective?
a. We need to code up our gestures. Also, we have a couple small issues to make mouse control more user-friendly. We are towards the end of our development and have started working on presentation materials as well.
4. How is your team functioning from your perspective?
a. Very well. We have sped up our development and are working a lot more efficiently.
5. What new ideas did you have or skills did you develop this week?
a. I did develop some skills in prototyping and circuit planning.
6. Who was your most awesome team member this week and why?
a. Will, Aaron, Grant, and Brint were very helpful this week.

Plans for Next Week
What are you going to work on this next week?
- Implement the gestures, fix minor useability issues with mouse control, fuse accelerometer data for mouse control. Also, do more user studies as we work throughout this week.

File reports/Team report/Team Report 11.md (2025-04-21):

**Team Weekly Report**

**Team:** The Gauntlet  
**Week:** 11  
**Members:** Kris Gavvala, [David Johnson](mailto:bluetech314@tamu.edu), [Aaron Martinez](mailto:aaron33@tamu.edu),  [Brint Nielson](mailto:brintcnielson@tamu.edu), [Will Tatum](mailto:willtaaa@tamu.edu), [Grant Turner](mailto:grantt731@tamu.edu)

| Status Report |
| :---- |

The team has made great progress and we believe we are close to finalzing the code, we just need to attempt to refine it to work better. We have gotten gesture code implemented it is just now down to refining it to work better. We continued to have issues with gesutures overlapping but we believe we have found a way to avoid most issues with that. We also once again had some hardware troubles but luckily we were easily able to fix it.

Our goal for this coming week is to complete our user studies and spend the remaining time refining the code. We want to use the feedback from our users to create the best experience possible while eliminating any bugs. 

| Current Status |
| :---- |

1. What did the team work on this past week?

| Task | Task Lead | Status | Notes |
| :---- | :---- | :---- | :---- |
| Integrated Gestures in polling loop | David | Complete |  |
| Gesture Detection | Will | In Progress | Fully in but needs refining |
| 3d print designs | Brint | In progress | Have designs just need to refine and print and then add  |
|  |  |  |  |
|  |  |  |  |

2. What feedback has the team received?

| From Whom | Feedback | Next Steps |
| :---- | :---- | :---- |
| Expo | Poster could use some addition for retroness | We will/have added the original name |
| Expo | Glove was surprisingly responsive but took some getting used to | Continue refining |
|  |  |  |

3. Are any resources needed? If so, what?
No resources needed.

| Plans for Next Week |
| :---- |

What are your plans for this next week?

| Task | Task Lead | Notes |
| :---- | :---- | :---- |
| Finish User Studies | Everyone |  |
| Finish gesture detection code refinement | Will |  |
| Refine Presentation | David |  |
| Practice presentation | Everyone |  |
| 3d Print | Brint |  |

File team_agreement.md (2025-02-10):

# Team Agreement

- The Gauntlet
- 01/27/2025

## Team Goals and Objectives

* Keep a good work ethic
* Reimagine the power glove for the modern era.
* Must keep design of original Power Glove
* The glove should output interpretable data which can be used by software such as a mouse or other controls.
* It should have the following features
    * Aiming
    * Right click
    * Left click
    * Scrolling
    * Zooming
    * Bluetooth connection
    * Turn off at a certain degree of elevation

Stretch goals:
* GUI for Controls
    * Design a GUI to allow a user to customize controls and preferences for their glove
    * Allow user to change what buttons do and what degree the glove turns off
    * Also allow user to customize gestures
* Additional Gestures recognized
    * Add additional gestures for the user to use to control their computer (ie Alt-tab)
* Integrate into a game
    * Be able to fully use glove to control a game
* Multiple mouse interpretations (wasd or laser pointer)
    * If possible allow user to also use the glove controls to control the cursor with buttons like wasd 

[^1]: **S**pecific, **M**easurable, **A**chievable, **R**elevant, **T**imeboxed

## Roles and Responsibilities

* David Johnson: Scrum Master
* Will Tatum: Computer Software Lead
* Aaron Martinez: Hardware Lead
* Brint Nielson: Driver Software Lead
* Grant Turner: Design Lead
* Kris Gavvala: Systems Integration Lead

## Communication Expectations

- Communicate with the group what work you have completed, began working on, and plan to start working on.
- If you must be unreliable, please at least communicate that with the group so we can pick up the slack. This is separate from unavailability, which should also be communicated to the group.
- Delegate roles or responsibilities in discord such that people can refer to it if needed.
  Use the separate discord chat channels accordingly.
- Communicate if you are unable to meet our reasonable expectations, such as if you are running late.

## Meeting Structure and Availability Expectations

- The start of Monday's class and the end of Wednesday's class will be the primary scheduled meeting. Any additional meetings will be impromptu messaging in Discord or a call if needed.
- Meetings will be, previous work, open comments, looking forward.

## Change Requests

- A majority vote is required to change the agreement, the professor can act as a tiebreaker ONLY when STRICTLY required.

## Team Agreement Maintenance

- Agreement meetings can take place as the team deems necessary.
- Somebody calls a need for change. During the review, the requestor will have a chance to persuade others in the group to agree and be open to rebuttals. We take a majority vote to see if it passes.
- We will review each bullet point and determine if current rules are still acceptable, need tweaking, or removed, or new rules need to be added.

## Team Member Signatures

* Aaron Martinez    
* Grant Turner
* David Johnson
* Will Tatum
* Kris A. Gavvala
* Brint Nielson

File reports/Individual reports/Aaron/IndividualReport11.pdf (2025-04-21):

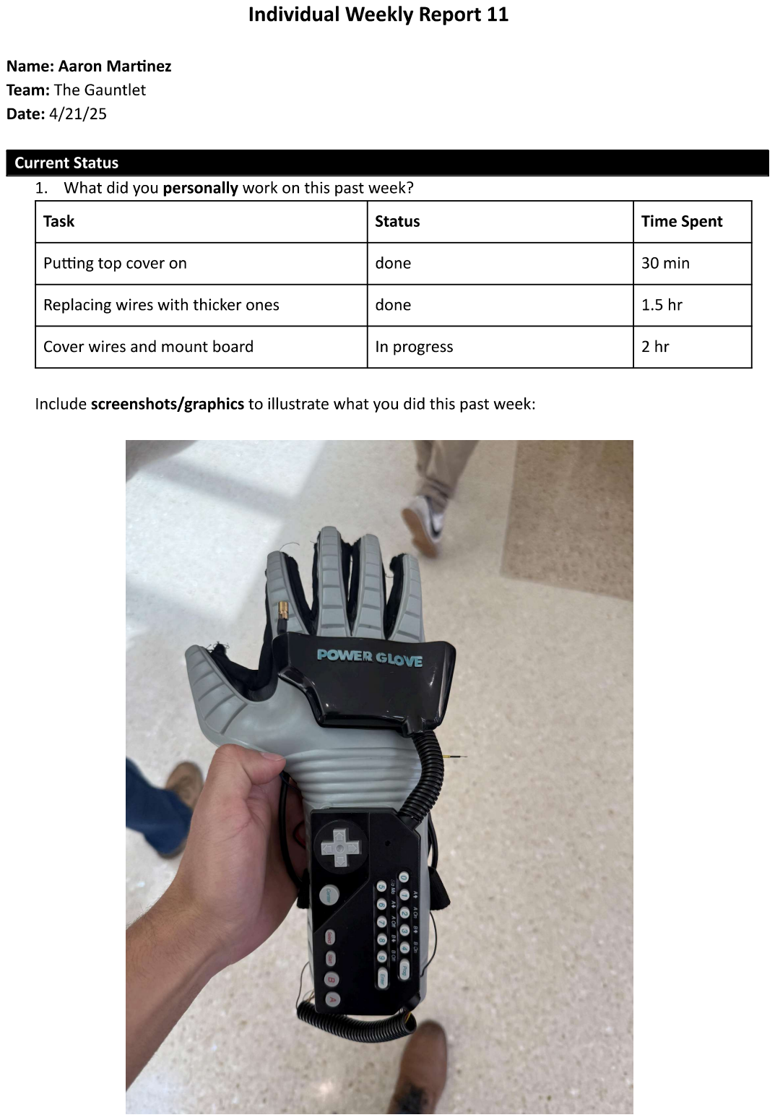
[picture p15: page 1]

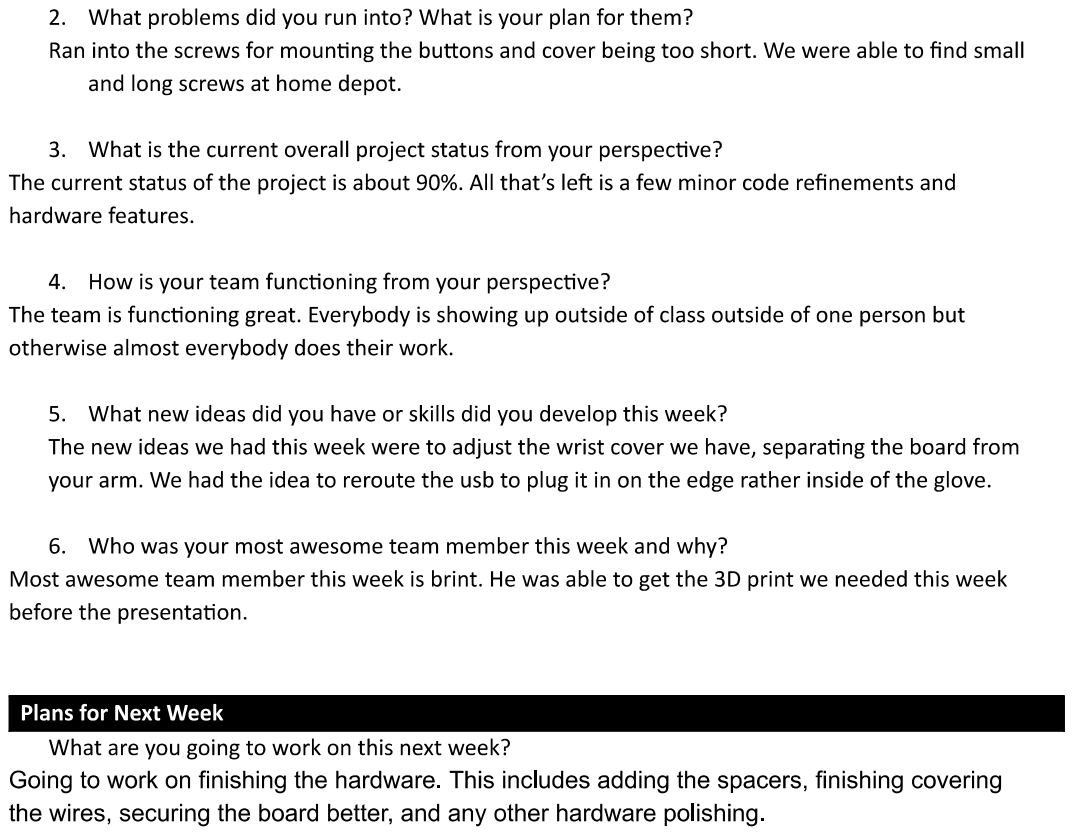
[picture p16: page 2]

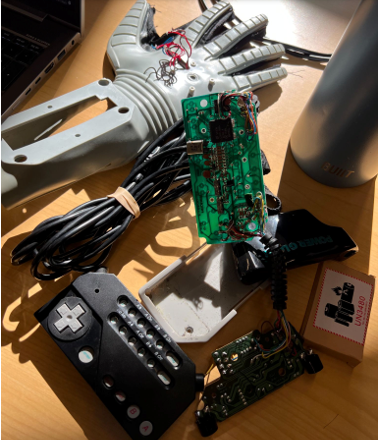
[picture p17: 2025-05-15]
images/original_glove.png

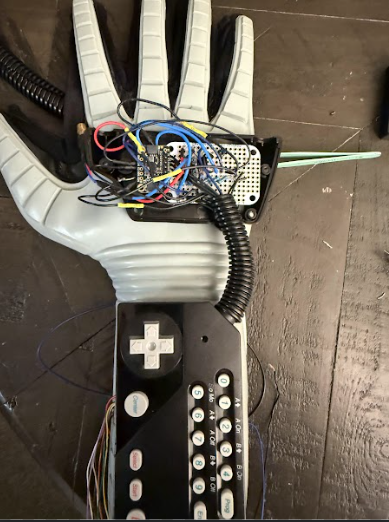
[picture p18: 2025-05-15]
images/top_internals.png

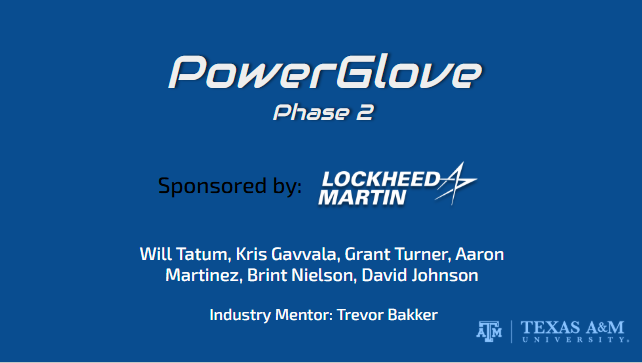
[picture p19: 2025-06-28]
images/title_slide.png

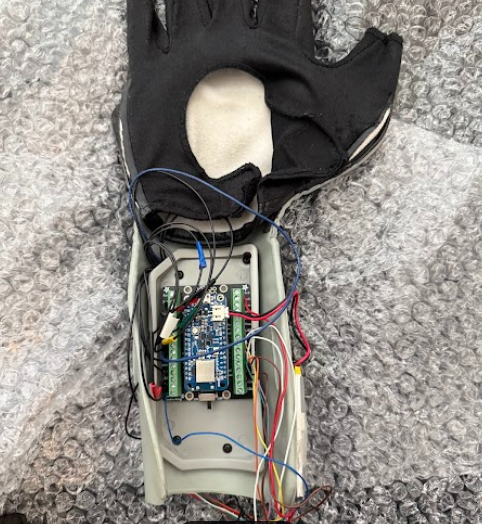
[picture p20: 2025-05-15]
images/bottom_internals.png

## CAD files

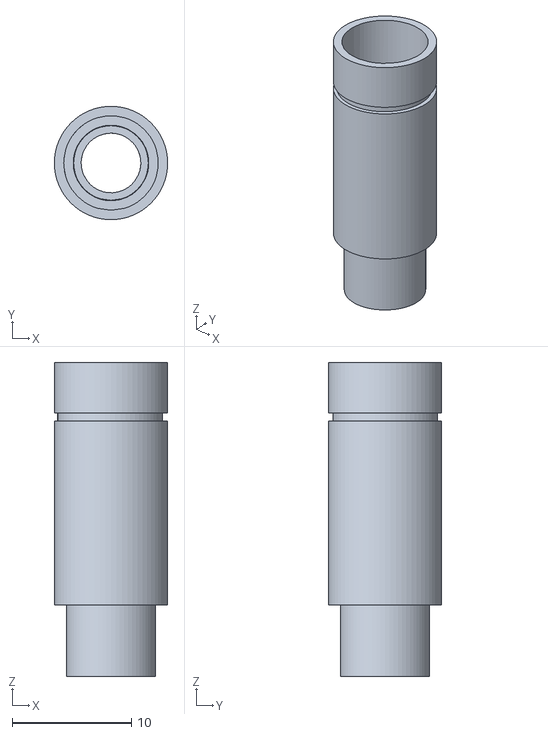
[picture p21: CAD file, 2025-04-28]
3d print artifacts/Laser pointer cover.stl
9.50 x 9.50 x 26.3

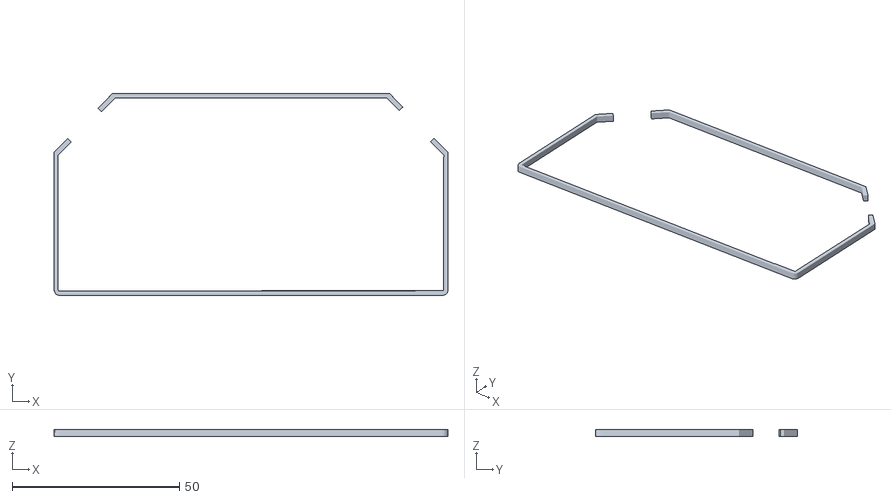
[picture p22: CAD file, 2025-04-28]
3d print artifacts/buttons spacer.stl
117.9 x 60.4 x 2.16

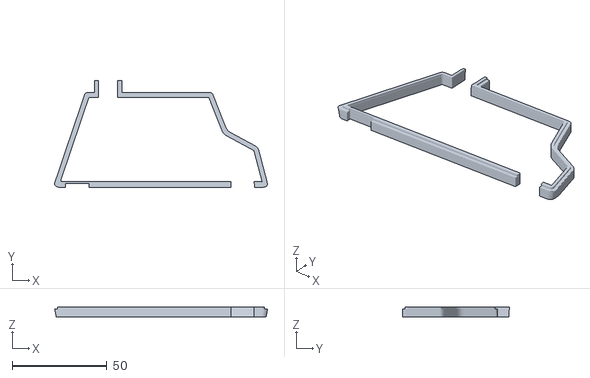
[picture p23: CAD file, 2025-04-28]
3d print artifacts/Backhand.stl
112.3 x 56.2 x 5.03

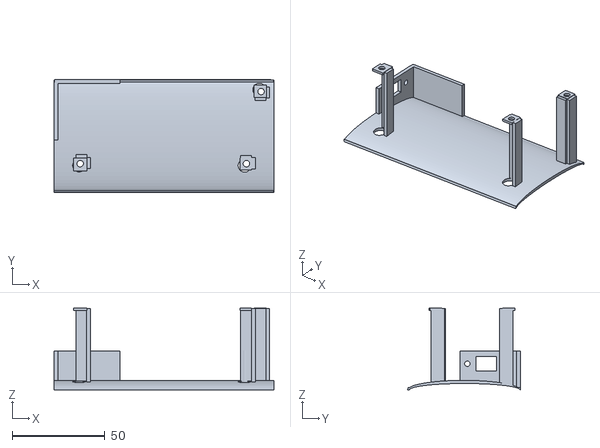
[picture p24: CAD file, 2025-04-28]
3d print artifacts/arduino guard.stl
118.9 x 61.1 x 44.3

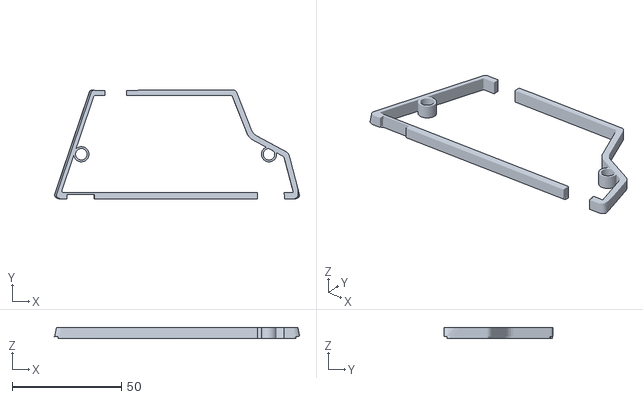
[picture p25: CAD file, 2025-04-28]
3d print artifacts/backhand space with screw holes.stl
112.3 x 50.0 x 5.00

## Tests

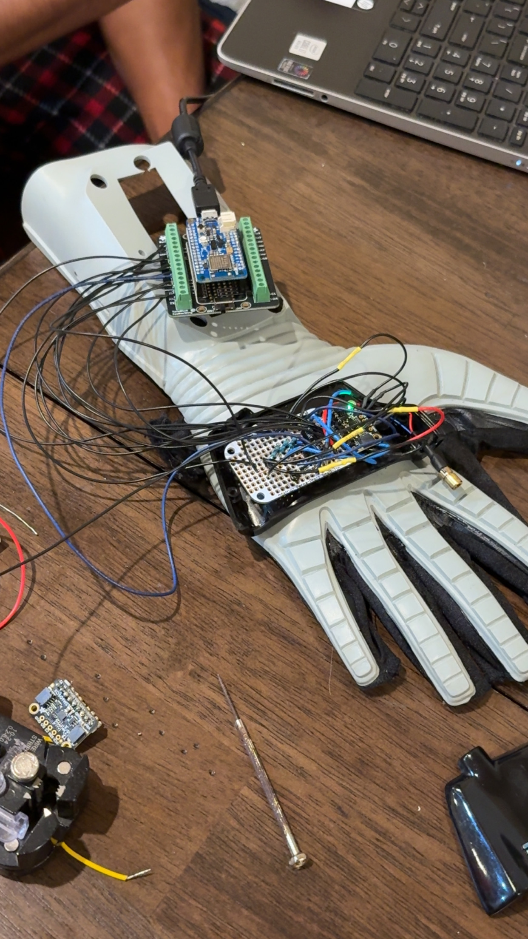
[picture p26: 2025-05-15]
images/testing.JPG

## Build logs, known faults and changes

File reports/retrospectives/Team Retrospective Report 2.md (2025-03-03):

**Team Retrospective Report**

**Team:** The Gauntlet  
**Retrospective Report \#:** 2  
**Members:** [David Johnson](mailto:bluetech314@tamu.edu), [Grant Turner](mailto:grantt731@tamu.edu), [Brint Nielson](mailto:brintcnielson@tamu.edu), [Aaron Martinez](mailto:aaron33@tamu.edu), [Will Tatum](mailto:willtaaa@tamu.edu), Kris Gavvala

| Current Status |
| :---- |

1. Give yourselves a pat on the back\! List the team’s accomplishments.

   The team managed to get the flex sensors in the glove and get them working with both left and right click. The team also implemented automated testing on GitHub and has been making good progress on getting the screen zoom and mouse scroll to work. The team also got progress on the glove buttons.

2. How is the team doing with communication? How will the team adjust going forward? 

   Overall communication has been good. We need to adjust by doing better with our task management in Jira.

3. How is the team doing with time? (Is the project on track, behind schedule, ahead of schedule?) How will the team adjust going forward?  
     
   We are on track to where we want to be. We have made good progress and will be able to work on stretch goals later down the road. The team will adjust by trying to get ahead in preparation for spring break.

| Keep doing | Start doing | Stop doing |
| :---- | :---- | :---- |
| Good communication | Better with Jira | Procrastinating |
| Working diligently |  |  |
| Dividing work |  |  |
|  |  |  |
|  |  |  |

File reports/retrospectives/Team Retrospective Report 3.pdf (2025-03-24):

### Team Retrospective Report

Team: The Gauntlet
Retrospective Report #: 3
Members: David Johnson , Grant Turner , Brint Nielson , Aaron Martinez , Will Tatum , Kris Gavvala

Current Status
1. Give yourselves a pat on the back! List the team’s accomplishments.

The team did a great job at getting hardware implemented along with the glove and a Kalman filter. It is a functional prototype and shows us where we need to put our work. We also started early on one of our stretch goals to make a GUI. Now we just need to finalize drivers to get that working. Overall got a lot done and allows us to work on refining mostly now with the hardware and software.

2. How is the team doing with communication? How will the team adjust going forward?

Overall communication has been good. We have improved but still need to improve more with Jira.

3. How is the team doing with time? (Is the project on track, behind schedule, ahead of schedule?) How will the team adjust going forward?

On track with the project and have a good prototype. We will just need to put in good work to ensure we finish strong in this next bit.

Keep doing | Start doing | Stop doing
Good communication | Better with Jira | Procrastinating
Working diligently | | Lacking occasionally in Jira
Dividing work
Putting in good progress

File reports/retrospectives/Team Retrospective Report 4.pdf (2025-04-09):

### Team Retrospective Report

Team: The Gauntlet
Retrospective Report #: 4
Members: David Johnson , Grant Turner , Brint Nielson , Aaron Martinez , Will Tatum , Kris Gavvala

Current Status
1. Give yourselves a pat on the back! List the team’s accomplishments.

The team did a great job at getting hardware onto the glove. We have some work on stretch goals that we can work on in the next week. We also got the glove circuitry looking nice and made a lot of progress on finalizing this project. We also have got some good testing in.

2. How is the team doing with communication? How will the team adjust going forward?

Overall communication has been good and has helped us get in good work out of class. We will keep doing our communication well and making sure to meet up when most of us are free outside of class.

3. How is the team doing with time? (Is the project on track, behind schedule, ahead of schedule?) How will the team adjust going forward?

Behind where we should be, we have integrated the hardware onto the glove but we need to test and make the glove look nicer.

Keep doing | Start doing | Stop doing
Putting in good work | Catching up on lack of progress | Lacking occasionally in Jira
Working outside of class time together | | Falling behind

Communicating well
Doing better at Jira

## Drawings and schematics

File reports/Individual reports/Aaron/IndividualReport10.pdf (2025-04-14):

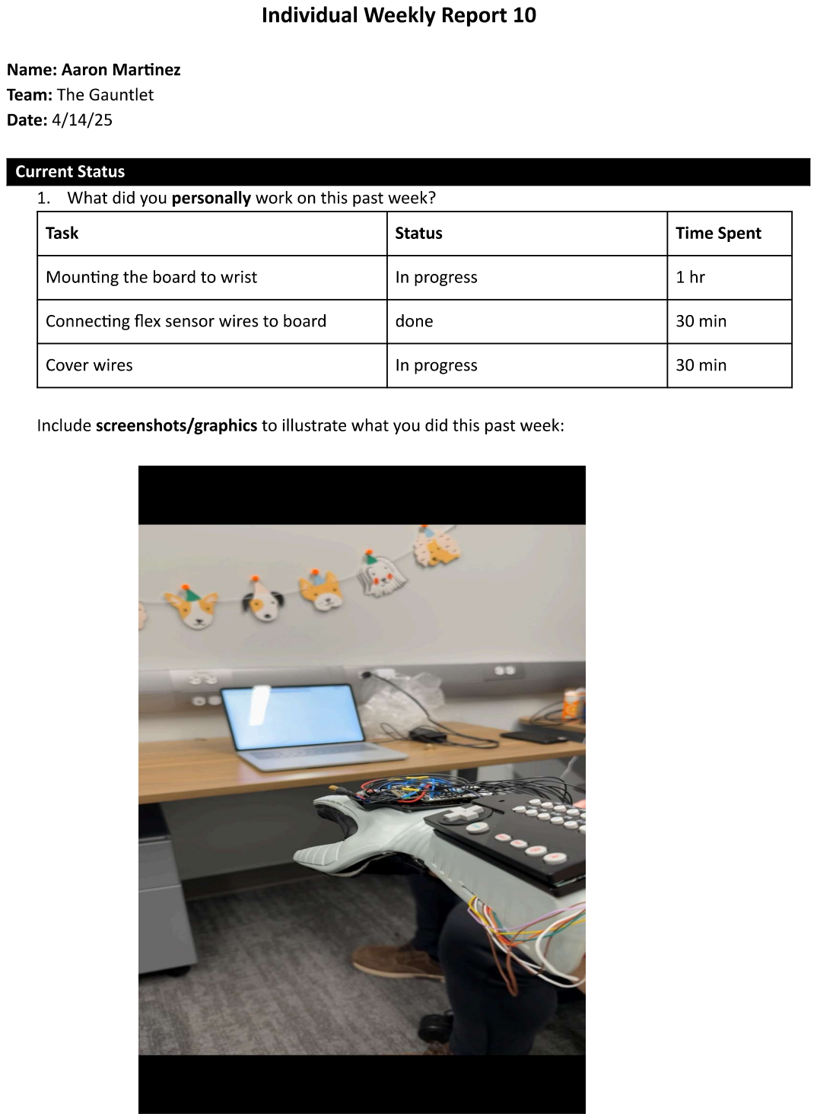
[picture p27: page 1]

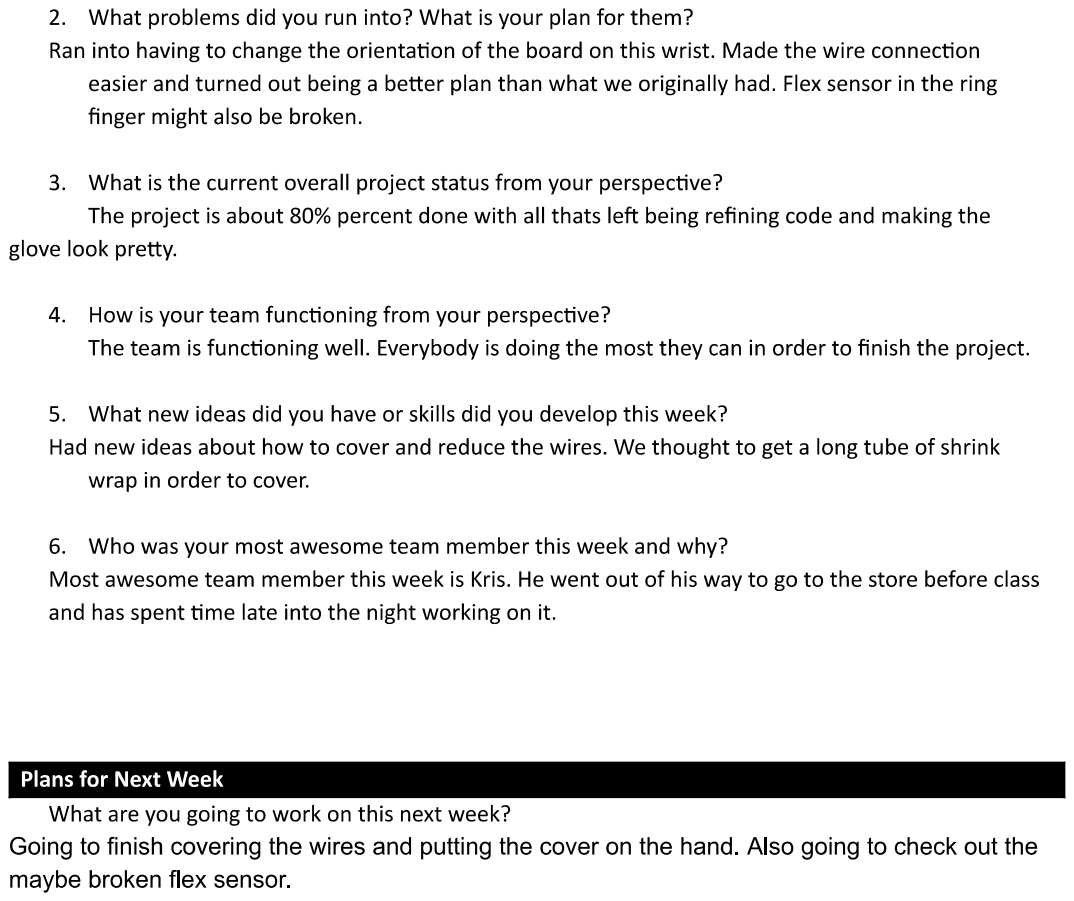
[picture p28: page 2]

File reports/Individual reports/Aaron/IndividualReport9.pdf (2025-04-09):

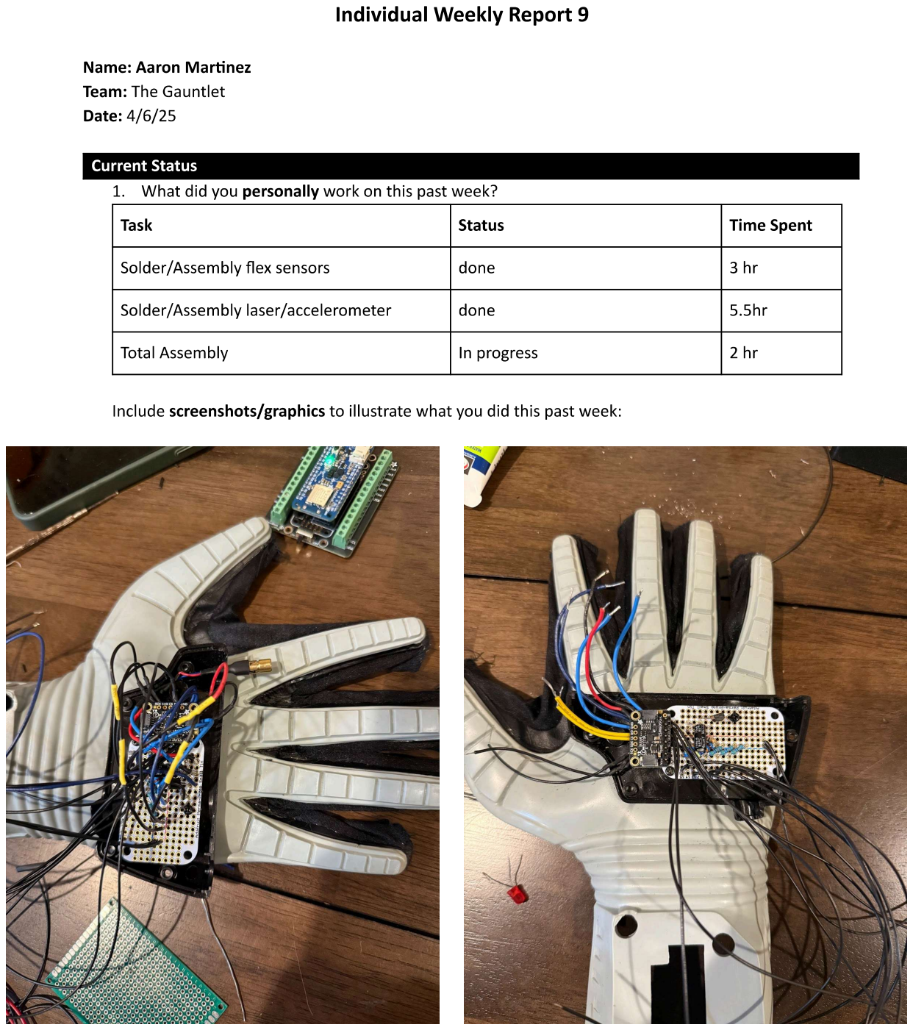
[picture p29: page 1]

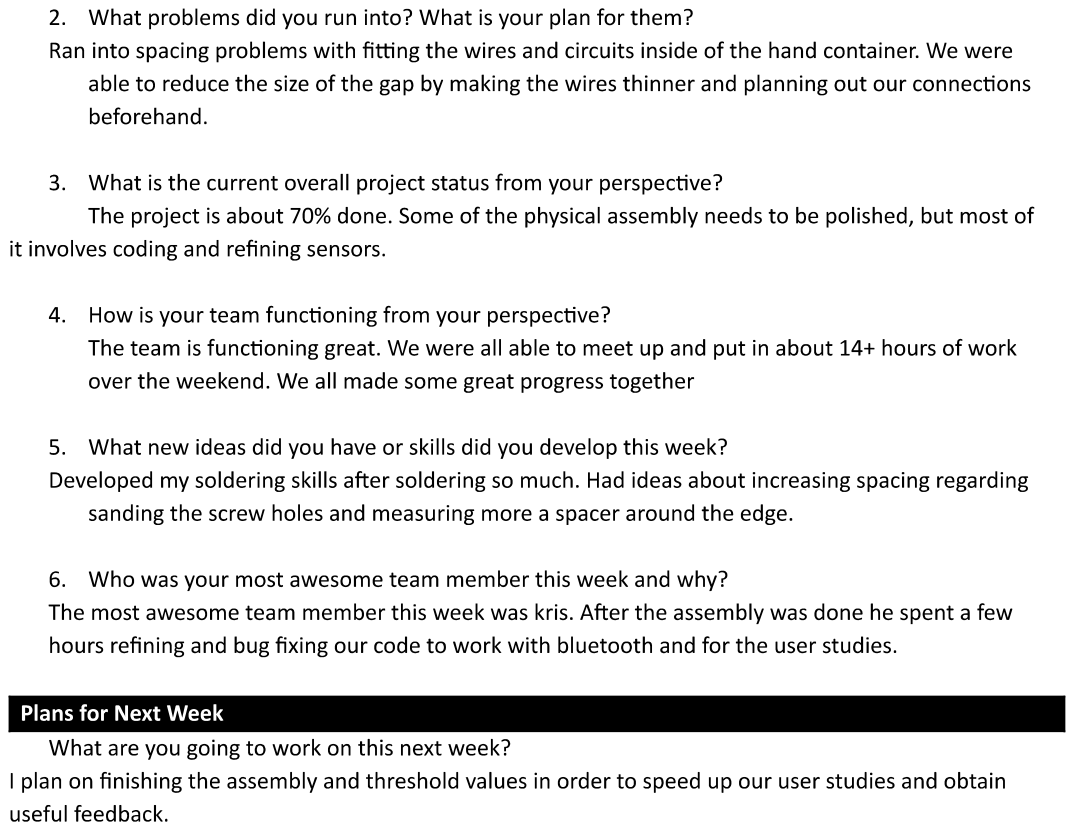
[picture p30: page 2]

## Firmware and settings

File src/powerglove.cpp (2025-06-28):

// #include <tinyekf.hpp>

/*this is an implementation of mouse control using the gyroscope of the LSM6DSOX IMU
An Extended Kalman Filter is used to smooth the acceleration values
which are scaled and used directly for control input
the KB2040 board was used to test this implmentation using usb hid and we are still
converting this to use on the feather nRF52840 sense board with BLe HID
  */

constexpr int EKF_MOTION_N = 4; //  States: Y lin Acc, X lin Acc, Y ang Vel, Z ang Vel,
constexpr int EKF_MOTION_M = 4; //  Measurements:  Y lin Acc, X lin Acc, Y ang Vel, Z ang Vel,

constexpr int EKF_FLEX_N = 5; // pointer, middle, thumb, ring, pinky
constexpr int EKF_FLEX_M = 5; // pointer, middle, thumb, ring, pinky

#include <bluefruit.h>
#include <Adafruit_LSM6DSOX.h>
#include <Adafruit_Sensor.h>
#include <tinyekf_motion.h>
#include <tinyekf_flex.h>
#include <gesture.h>
#include <math.h>
#include <Adafruit_TinyUSB.h>

BLEDis bledis;
BLEHidAdafruit blehid;

// predeclare functions
void configBluetooth(void);
void startAdv(void);

// sensor variables
float indexFiltered = 0.0;
float middleFiltered = 0.0;
float thumbFiltered = 0.0;
float pinkyFiltered = 0.0;
float ringFiltered = 0.0;

int middleFinger;
int indexFinger;
int thumb;
int ringFinger;
int pinkyFinger;

float my = 0.0; // mouse movement
float mz = 0.0;

float ax = 0.0; // raw acceleration
float ay = 0.0;

float a_x = 0.0; // filtered acc
float a_y = 0.0;

float gy = 0.0; // raw gyroscope values
float gz = 0.0;

sensors_event_t accel;
sensors_event_t gyro;
sensors_event_t temp;
// end motion variables

// motion filter
static const float EPS = 1e-6;

static const float Pdiag[EKF_MOTION_N] = {0.001, 0.001, 0.001, 0.001};

static const float Q[EKF_MOTION_N * EKF_MOTION_N] = {

    EPS, 0, 0, 0,
    0, EPS, 0, 0,
    0, 0, EPS, 0,
    0, 0, 0, EPS};

static const float ER[EKF_MOTION_M * EKF_MOTION_M] = {
    // USED TO BE THE R MATRIX
    0.002, 0, 0, 0,
    0, 0.002, 0, 0,
    0, 0, 0.002, 0,
    0, 0, 0, 0.002};

static const float H[EKF_MOTION_M * EKF_MOTION_N] = {
    1, 0, 0, 0,
    0, 1, 0, 0,
    0, 0, 1, 0,
    0, 0, 0, 1};

static ekf_t_motion _ekf;

// flex sensor filter
static const float EPS_ = 1e-6;

static const float Pdiag_flex[EKF_FLEX_N] = {0.001, 0.001, 0.001, 0.001, 0.001};

static const float Q_flex[EKF_FLEX_N * EKF_FLEX_N] = {
    EPS_, 0, 0, 0, 0,
    0, EPS_, 0, 0, 0,
    0, 0, EPS_, 0, 0,
    0, 0, 0, EPS_, 0,
    0, 0, 0, 0, 1e-10};

static const float ER_flex[EKF_FLEX_M * EKF_FLEX_M] = {
    // USED TO BE THE R MATRIX
    0.002, 0, 0, 0, 0,
    0, 0.002, 0, 0, 0,
    0, 0, 0.002, 0, 0,
    0, 0, 0, 0.002, 0,
    0, 0, 0, 0, 0.1};

static const float H_flex[EKF_FLEX_M * EKF_FLEX_N] = {
    1, 0, 0, 0, 0,
    0, 1, 0, 0, 0,
    0, 0, 1, 0, 0,
    0, 0, 0, 1, 0,
    0, 0, 0, 0, 1};

static ekf_t_flex _ekf_flex;

Adafruit_LSM6DSOX sox;
float prev = 0.0;
float curr = 0.0;
float dt = 0.01;

// constexpr int MIDDLE_FINGER_PIN = A0;
// constexpr int INDEX_FINGER_PIN = A1;
// constexpr int THUMB_PIN = A2;
// constexpr int RING_FINGER_PIN = A5;
// constexpr int PINKY_FINGER_PIN = A4;

// needed for gesture key presses
uint8_t emptyKeycode[6] = {0};
uint8_t activeKey[6] = {0};

bool mouseEnabled = true;
bool toggleMouse = false;

constexpr Gestures LEFT_CLICK_GESTURE = I;
constexpr Gestures RIGHT_CLICK_GESTURE = M;
constexpr Gestures DRAG_GESTURE = TI;
constexpr Gestures LASER_GESTURE = T;
constexpr Gestures DISABLE_MOUSE_GESTURE = TIMRP;
constexpr Gestures SNIP_GESTURE = TMRP;
constexpr Gestures ALT_F4_GESTURE = TIRP;
constexpr Gestures ALT_TAB_GESTURE = MRP;
constexpr Gestures WIN_TAB_GESTURE = IRP;
constexpr Gestures ZOOM_GESTURE = TP;
constexpr Gestures SCROLL_GESTURE = TRP;

int MOUSE_SENSITIVITY = 20;

constexpr float oneThousandth = 1.0 / 1000.0;

enum GestureState
{
    IDLE,
    LEFT_CLICK_EVENT,
    RIGHT_CLICK_EVENT,
    DRAG_EVENT,
    LASER,
    SNIP,
    // ALT_F4,
    ALT_TAB,
    WIN_TAB,
    DISABLE_MOUSE,
    ZOOM,
    SCROLL
};

GestureState gestureState = IDLE;
Gestures previousGesture = NONE;
Gestures currentGesture = NONE;

const int button_none[] = {1, 0, 0, 0, 0, 0, 0, 0, 0};
const int button0[] = {1, 0, 0, 0, 0, 0, 1, 0, 1};
const int button1[] = {1, 0, 0, 0, 0, 1, 1, 0, 1};
const int button2[] = {1, 0, 0, 0, 0, 0, 1, 1, 1};
const int button3[] = {1, 1, 0, 0, 1, 0, 0, 0, 0};
const int button4[] = {1, 1, 0, 1, 1, 0, 0, 0, 0};
const int button5[] = {1, 0, 0, 0, 0, 1, 1, 1, 0};
const int button6[] = {1, 0, 0, 0, 0, 1, 1, 1, 1};
const int button7[] = {1, 0, 0, 0, 1, 0, 0, 0, 0};
const int button8[] = {1, 0, 0, 1, 1, 0, 0, 0, 0};
const int button9[] = {1, 0, 1, 0, 1, 0, 0, 0, 0};
const int buttonProg[] = {1, 1, 1, 1, 1, 0, 0, 0, 0};
const int buttonEnter[] = {1, 0, 1, 1, 1, 0, 0, 0, 0};
const int leftArrow[] = {1, 0, 0, 0, 0, 1, 1, 0, 0};
const int upArrow[] = {1, 0, 0, 0, 0, 0, 1, 1, 0};
const int rightArrow[] = {1, 0, 0, 0, 0, 0, 1, 0, 0};
const int downArrow[] = {1, 0, 0, 0, 0, 1, 0, 1, 1};
const int buttonCenter[] = {1, 0, 0, 0, 0, 0, 0, 1, 1};
const int buttonSelect[] = {1, 1, 1, 1, 0, 0, 0, 0, 0};
const int buttonStart[] = {1, 1, 1, 0, 0, 0, 0, 0, 0};
const int buttonB[] = {1, 1, 1, 0, 1, 0, 0, 0, 0};
const int buttonA[] = {0, 0, 0, 0, 0, 0, 0, 0, 0};
const int numButtons = 21;

const int *buttonSignatures[] = {
    button0, button1, button2, button3, button4, button5, button6,
    button7, button8, button9, buttonProg, buttonEnter, leftArrow,
    upArrow, rightArrow, downArrow, buttonCenter, buttonSelect,
    buttonStart, buttonB, buttonA};

// const char *buttonNames[] = {
//     "Button 0", "Button 1", "Button 2", "Button 3", "Button 4",
//     "Button 5", "Button 6", "Button 7", "Button 8", "Button 9",
//     "Button Prog", "Button Enter", "Left Arrow", "Up Arrow",
//     "Right Arrow", "Down Arrow", "Button Center", "Button Select",
//     "Button Start", "Button B", "Button A"};

const int inputPins[] = {2, 5, 6, 9, 10, 11, 12, 13, 23};
const int numPins = 9;
int pinReadings[numPins];

bool pressed = false;
bool program = false;

// Find what button is being pressed
int matchButton(const int *pinReadings)
{
    // Check if no button is pressed and return to save time
    bool none = true;
    for (int i = 0; i < numPins; i++)
    {
        if (button_none[i] != pinReadings[i])
        {
            none = false;
            break;
        }
    }

    if (none)
    {
        return -1;
    }

    for (int i = 0; i < numButtons; i++)
    {
        bool match = true;
        for (int j = 0; j < numPins; j++)
        {
            if (pinReadings[j] != buttonSignatures[i][j])
            {
                match = false;
                break;
            }
        }
        if (match)
            return i;
    }
    return -1;
}

// Function to send windows key + number or other key depending on button pressed
void pressModifierAndKey(uint8_t number)
{
    int modifier = 0x08;            // windows key
    if (number >= 0 && number <= 9) // windows plus num 1-9
    {
        activeKey[0] = HID_KEY_1 + number; // 0x1E
    }
    else if (number == 11) // enter = win + l
    {
        activeKey[0] = HID_KEY_L;
    }
    else if (number == 12) // left arrow = win + tab
    {
        activeKey[0] = HID_KEY_TAB;
    }
    else if (number == 13) // up arrow = alt + f4
    {
        modifier = KEYBOARD_MODIFIER_LEFTALT;
        activeKey[0] = HID_KEY_F4; // 0x2B
    }
    else if (number == 14) // right arrow = alt + tab
    {
        modifier = KEYBOARD_MODIFIER_LEFTALT; // 0x04
        activeKey[0] = HID_KEY_TAB;
    }
    else if (number == 15) // down arrow = win + d
    {
        activeKey[0] = HID_KEY_D; // 0x07
    }
    else if (number == 17) // select = win + shift + s (snipping tool)
    {
        modifier = modifier | KEYBOARD_MODIFIER_LEFTSHIFT; // windows + shift
        activeKey[0] = HID_KEY_S;                          // 0x16
    }
    else if (number == 18)
    {
        activeKey[0] = HID_KEY_E;
    }
    else if (number == 19) // B button = ctrl + v
    {
        modifier = KEYBOARD_MODIFIER_LEFTCTRL; // l-ctrl
        activeKey[0] = HID_KEY_V;              // 0x19
    }
    else if (number == 20) // A button = ctrl + c
    {
        modifier = KEYBOARD_MODIFIER_LEFTCTRL; // l-ctrl
        activeKey[0] = HID_KEY_C;              // 0x06
    }
    blehid.keyboardReport(BLE_CONN_HANDLE_INVALID, modifier, activeKey);
    blehid.keyRelease();
}

// the setup routine runs once when you press reset:
void setup()
{

    Serial.begin(115200);
    while (!Serial)
    {
        Serial.println("cannot proceed!");
        delay(10);
    }

    // Serial.println("Motion Control Glove - Starting");

    ekf_initialize_motion(&_ekf, Pdiag);
    ekf_initialize_flex(&_ekf_flex, Pdiag_flex);

    if (!sox.begin_SPI(1))
    {
        // if (!sox.begin_SPI(LSM_CS, LSM_SCK, LSM_MISO, LSM_MOSI)) {
        // Serial.println("Failed to find LSM6DSOX chip");
        while (1)
        {
            delay(10);
        }
    }
    // Serial.println("LSM6DSOX Found!");
    // Configure accelerometer/gyroscope
    sox.setAccelRange(LSM6DS_ACCEL_RANGE_2_G);
    sox.setGyroRange(LSM6DS_GYRO_RANGE_250_DPS);
    sox.setAccelDataRate(LSM6DS_RATE_208_HZ);
    sox.setGyroDataRate(LSM6DS_RATE_208_HZ);

    configBluetooth();

    Bluefruit.begin();
    Bluefruit.setTxPower(4); // Check bluefruit.h for supported values

    // Configure and Start Device Information Service
    bledis.setManufacturer("Adafruit Industries");
    bledis.setModel("Bluefruit Feather 52");
    bledis.begin();

    // BLE HID
    blehid.begin();

    // Initialize button input pins
    for (int i = 0; i < numPins; i++)
    {
        pinMode(inputPins[i], INPUT);
    }

    // Set up and start advertising
    startAdv();
    pinMode(22, OUTPUT); // move the laser to a digital pin instead of analog
    digitalWrite(22, LOW);
}

void getMotionData()
{
    sox.getEvent(&accel, &gyro, &temp);

    ax = accel.acceleration.x + 0.95;
    ay = accel.acceleration.y - 0.95;
    // az = accel.acceleration.z - 10.03;

    // gx = gyro.gyro.x;
    gy = 0.01 + gyro.gyro.y;
    gz = 0.01 + gyro.gyro.z;

    const float z[EKF_MOTION_M] = {ay, ax, gy, gz};

    // const float z[EKF_MOTION_M] = {gy, gz, indexFinger, middleFinger, thumb, ringFinger};
    const float F[EKF_MOTION_N * EKF_MOTION_N] = {
        1, 0, 0, 0,
        0, 1, 0, 0,
        0, 0, 1, 0,
        0, 0, 0, 1};

    // Process model f(x)
    const float fx[EKF_MOTION_N] = {_ekf.x[0], _ekf.x[1], _ekf.x[2], _ekf.x[3]};

    // Run the prediction step of the eKF
    ekf_predict_motion(&_ekf, fx, F, Q);

    const float hx[EKF_MOTION_M] = {_ekf.x[0], _ekf.x[1], _ekf.x[2], _ekf.x[3]};

    // Run the update step
    ekf_update_motion(&_ekf, z, hx, H, ER);
}

void getFlexData()
{
    middleFinger = analogRead(A0);
    indexFinger = analogRead(A1);
    thumb = analogRead(A2);
    ringFinger = analogRead(A4);
    pinkyFinger = analogRead(A5);

    const float z[EKF_FLEX_M] = {thumb, indexFinger, middleFinger, ringFinger, pinkyFinger};

    // const float z[EKF_MOTION_M] = {gy, gz, indexFinger, middleFinger, thumb, ringFinger};
    const float F[EKF_FLEX_N * EKF_FLEX_N] = {
        1, 0, 0, 0, 0,
        0, 1, 0, 0, 0,
        0, 0, 1, 0, 0,
        0, 0, 0, 1, 0,
        0, 0, 0, 1, 1};

    // Process model f(x)
    const float fx[EKF_FLEX_N] = {_ekf_flex.x[0], _ekf_flex.x[1], _ekf_flex.x[2], _ekf_flex.x[3], _ekf_flex.x[4]};

    // Run the prediction step of the eKF
    ekf_predict_flex(&_ekf_flex, fx, F, Q_flex);

    const float hx[EKF_FLEX_M] = {_ekf_flex.x[0], _ekf_flex.x[1], _ekf_flex.x[2], _ekf_flex.x[3], _ekf_flex.x[4]};

    // Run the update step
    ekf_update_flex(&_ekf_flex, z, hx, H_flex, ER_flex);
}

// the loop routine runs over and over again forever:
void loop()
{
    curr = millis();

    dt = (curr - prev) * oneThousandth;
    prev = curr;

    getMotionData();
    getFlexData();

    // scale the acceleration values by 20
    /*the scaling factor was empiricaly determined. We need to find why this works
    to see if there may be a more optimal value*/

    my = MOUSE_SENSITIVITY * _ekf.x[2];
    mz = -MOUSE_SENSITIVITY * _ekf.x[3];
    a_x = _ekf.x[1];

    thumbFiltered = _ekf_flex.x[0];
    indexFiltered = _ekf_flex.x[1];
    middleFiltered = _ekf_flex.x[2];

    ringFiltered = _ekf_flex.x[3];
    pinkyFiltered = _ekf_flex.x[4];

    if (mouseEnabled)
    {
        blehid.mouseMove(mz, my);
    }

    ////
    ////GESTURE TESTING
    previousGesture = currentGesture;
    // currentGesture = NONE;
    currentGesture = gesture(thumbFiltered, indexFiltered, middleFiltered, ringFiltered, pinkyFiltered);
    // currentGesture = gesture(thumb, indexFinger, middleFinger, ringFinger, pinkyFinger);

    // Serial.println(a_x);

    switch (gestureState)
    {
    case IDLE:
        if (currentGesture == DRAG_GESTURE)
        {
            blehid.mouseButtonPress(MOUSE_BUTTON_LEFT);
            gestureState = DRAG_EVENT;
        }

        else if (currentGesture == LEFT_CLICK_GESTURE)
        {
            blehid.mouseButtonPress(MOUSE_BUTTON_LEFT);
            gestureState = LEFT_CLICK_EVENT;
            mouseEnabled = false;
        }

        else if (currentGesture == RIGHT_CLICK_GESTURE)
        {
            blehid.mouseButtonPress(MOUSE_BUTTON_RIGHT);
            gestureState = RIGHT_CLICK_EVENT;
            mouseEnabled = false;
        }

        else if (currentGesture == LASER_GESTURE)
        {
            mouseEnabled = false;
            digitalWrite(22, HIGH);
            gestureState = LASER;
        }

        else if (currentGesture == DISABLE_MOUSE_GESTURE)
        {
            toggleMouse = !toggleMouse;
            mouseEnabled = false;
            gestureState = DISABLE_MOUSE;
        }

        else if (currentGesture == SNIP_GESTURE)
        {
            activeKey[0] = HID_KEY_S; // 0x16
            // 0xA should work (left shift + left windows)
            blehid.keyboardReport(BLE_CONN_HANDLE_INVALID, KEYBOARD_MODIFIER_LEFTSHIFT + KEYBOARD_MODIFIER_LEFTGUI, activeKey); // previously 0x28
            gestureState = SNIP;
        }

        // else if (currentGesture == ALT_F4_GESTURE)
        // {
        //   mouseEnabled = false;
        //   activeKey[0] = HID_KEY_F4;                                                            // 0x3D
        //   blehid.keyboardReport(BLE_CONN_HANDLE_INVALID, KEYBOARD_MODIFIER_LEFTALT, activeKey); // 0x04
        //   gestureState = ALT_F4;
        // }

        else if (currentGesture == ALT_TAB_GESTURE)
        {
            mouseEnabled = false;
            activeKey[0] = HID_KEY_TAB;                                                           // 0x2B
            blehid.keyboardReport(BLE_CONN_HANDLE_INVALID, KEYBOARD_MODIFIER_LEFTALT, activeKey); // 0x04
            gestureState = ALT_TAB;
        }

        else if (currentGesture == WIN_TAB_GESTURE)
        {
            mouseEnabled = false;
            activeKey[0] = HID_KEY_TAB; // 0x2B
            // 0x6 should work (left alt + left shift)
            blehid.keyboardReport(BLE_CONN_HANDLE_INVALID, KEYBOARD_MODIFIER_LEFTGUI, activeKey); // previously 0x24
            gestureState = WIN_TAB;
        }

        else if (currentGesture == SCROLL_GESTURE)
        {
            mouseEnabled = false;

            // scroll up
            if (a_x > 2)
            {
                blehid.mouseScroll(1);
                // delay(200);
                gestureState = SCROLL;
            }

            // scroll down
            else if (a_x < -2)
            {
                blehid.mouseScroll(-1);
                // delay(200);
                gestureState = SCROLL;
            }
        }

        else if (currentGesture == ZOOM_GESTURE)
        {
            mouseEnabled = false;

            // zoom in
            if (a_x > 2)
            {
                blehid.keyboardReport(BLE_CONN_HANDLE_INVALID, KEYBOARD_MODIFIER_LEFTCTRL, emptyKeycode); // 0x01
                blehid.mouseScroll(-1);
                // delay(300);
                gestureState = ZOOM;
            }

            // zoom out
            else if (a_x < -2)
            {
                blehid.keyboardReport(BLE_CONN_HANDLE_INVALID, KEYBOARD_MODIFIER_LEFTCTRL, emptyKeycode); // 0x01
                blehid.mouseScroll(1);
                // delay(300);
                gestureState = ZOOM;
            }
        }
        break;

    case LEFT_CLICK_EVENT:
        if (currentGesture == NONE)
        {
            mouseEnabled = true;
            blehid.mouseButtonRelease(MOUSE_BUTTON_LEFT);
            gestureState = IDLE;
        }
        else if (previousGesture != currentGesture)
        {
            mouseEnabled = true;
            gestureState = IDLE;
        }
        break;

    case RIGHT_CLICK_EVENT:
        if (currentGesture == NONE)
        {
            mouseEnabled = true;
            blehid.mouseButtonRelease(MOUSE_BUTTON_RIGHT);
            gestureState = IDLE;
        }
        else if (previousGesture != currentGesture)
        {
            mouseEnabled = true;
            gestureState = IDLE;
        }
        break;

    case DRAG_EVENT:
        if (currentGesture == NONE || previousGesture != currentGesture)
        {
            blehid.mouseButtonRelease(MOUSE_BUTTON_LEFT);
            gestureState = IDLE;
        }
        break;

    case LASER:
        if (currentGesture == NONE || previousGesture != currentGesture)
        {
            mouseEnabled = true;
            digitalWrite(22, LOW);
            gestureState = IDLE;
        }
        break;

    case DISABLE_MOUSE:
        if (!toggleMouse)
        {
            mouseEnabled = true;
        }
        gestureState = IDLE;
        break;

    case SNIP:
        if (currentGesture == NONE || previousGesture != currentGesture)
        {
            blehid.keyboardReport(BLE_CONN_HANDLE_INVALID, HID_KEY_NONE, emptyKeycode); // 0
            blehid.keyRelease();
            gestureState = IDLE;
        }
        break;

        // case ALT_F4:
        //   if (currentGesture == NONE || previousGesture != currentGesture)
        //   {
        //     blehid.keyboardReport(BLE_CONN_HANDLE_INVALID, HID_KEY_NONE, emptyKeycode); // 0
        //     blehid.keyRelease();
        //     gestureState = IDLE;
        //   }
        //   break;

    case ALT_TAB:
        if (currentGesture == NONE || previousGesture != currentGesture)
        {
            blehid.keyboardReport(BLE_CONN_HANDLE_INVALID, HID_KEY_NONE, emptyKeycode); // 0
            blehid.keyRelease();
            gestureState = IDLE;
        }
        break;

    case WIN_TAB:
        if (currentGesture == NONE || previousGesture != currentGesture)
        {
            blehid.keyboardReport(BLE_CONN_HANDLE_INVALID, HID_KEY_NONE, emptyKeycode); // 0
            blehid.keyRelease();
            gestureState = IDLE;
        }
        break;

    case SCROLL:
        if (currentGesture == NONE || previousGesture != currentGesture)
        {
            mouseEnabled = true;
            blehid.mouseScroll(0);
            gestureState = IDLE;
            break;
        }

        // scroll up
        if (a_x > 2)
        {
            blehid.mouseScroll(1);
            delay(300);
        }

        // scroll down
        else if (a_x < -2)
        {
            blehid.mouseScroll(-1);
            delay(300);
        }
        else
        {
            blehid.mouseScroll(0);
            // blehid.keyboardReport(BLE_CONN_HANDLE_INVALID, HID_KEY_NONE, emptyKeycode); // 0
            // blehid.keyRelease();
            // mouseEnabled = true;
            // gestureState = IDLE;
            // break;
        }

        break;

    case ZOOM:

        if (currentGesture == NONE || previousGesture != currentGesture)
        {
            blehid.mouseScroll(0);
            blehid.keyboardReport(BLE_CONN_HANDLE_INVALID, HID_KEY_NONE, emptyKeycode); // 0
            blehid.keyRelease();
            mouseEnabled = true;
            gestureState = IDLE;
            break;
        }

        if (a_x > 2)
        {
            blehid.keyboardReport(BLE_CONN_HANDLE_INVALID, KEYBOARD_MODIFIER_LEFTCTRL, emptyKeycode); // 0x01
            blehid.mouseScroll(-1);
            delay(400);
        }

        // zoom out
        else if (a_x < -2)
        {
            blehid.keyboardReport(BLE_CONN_HANDLE_INVALID, KEYBOARD_MODIFIER_LEFTCTRL, emptyKeycode); // 0x01
            blehid.mouseScroll(1);
            delay(400);
        }
        else
        {
            blehid.mouseScroll(0);
            // blehid.keyboardReport(BLE_CONN_HANDLE_INVALID, HID_KEY_NONE, emptyKeycode); // 0
            // blehid.keyRelease();
            // mouseEnabled = true;
            // gestureState = IDLE;
            // break;
        }

        break;
    }

    // Handle buttons
    // Read buttons
    for (int i = 0; i < numPins; i++)
    {
        pinReadings[i] = digitalRead(inputPins[i]);
    }

    int index = matchButton(pinReadings);

    // if (index != -1)
    // {
    // Serial.print("Detected: ");
    // Serial.println(buttonNames[index]);
    // }

    if (!pressed)
    {
        if ((index >= 0 && index <= 9) || index == 11 || index == 12 || index == 14 || index == 17 || index == 18 || index == 19 || index == 20)
        {
            pressModifierAndKey(index);
            pressed = true;
            delay(100);
        }

        switch (index)
        {
        case 10: // prog button
            program = !program;
            pressed = true;
            delay(100);
            break;

        case 13: // up arrow = win+tab (task view)      // CHANGE TO ALT F4
            if (program)
            {
                if (MOUSE_SENSITIVITY < 50)
                    MOUSE_SENSITIVITY++;
                delay(100);
                break;
            }
            pressModifierAndKey(index);
            pressed = true;
            delay(100);
            break;
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

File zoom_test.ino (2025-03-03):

/*********************************************************************
 This is an example for our nRF52 based Bluefruit LE modules

 Pick one up today in the adafruit shop!

 Adafruit invests time and resources providing this open source code,
 please support Adafruit and open-source hardware by purchasing
 products from Adafruit!

 MIT license, check LICENSE for more information
 All text above, and the splash screen below must be included in
 any redistribution
*********************************************************************/
#include <bluefruit.h>

BLEDis bledis;
BLEHidAdafruit blehid;

#define MOVE_STEP    10

void setup() 
{
  Serial.begin(115200);
  while ( !Serial ) delay(10);   // for nrf52840 with native usb

  Serial.println("Bluefruit52 HID Mouse Example");
  Serial.println("-----------------------------\n");
  Serial.println("Go to your phone's Bluetooth settings to pair your device");
  Serial.println("then open an application that accepts mouse input");
  Serial.println();

  Serial.println("Enter following characters");
  Serial.println("- 'WASD'  to move mouse (up, left, down, right)");
  Serial.println("- 'LRMBF' to press mouse button(s) (left, right, middle, backward, forward)");
  Serial.println("- 'X'     to release mouse button(s)");

  Bluefruit.begin();
  // HID Device can have a min connection interval of 9*1.25 = 11.25 ms
  Bluefruit.Periph.setConnInterval(9, 16); // min = 9*1.25=11.25 ms, max = 16*1.25=20ms
  Bluefruit.setTxPower(4);    // Check bluefruit.h for supported values

  // Configure and Start Device Information Service
  bledis.setManufacturer("Adafruit Industries");
  bledis.setModel("Bluefruit Feather 52");
  bledis.begin();

  // BLE HID
  blehid.begin();

  // Set up and start advertising
  startAdv();
}

void startAdv(void)
{  
  // Advertising packet
  Bluefruit.Advertising.addFlags(BLE_GAP_ADV_FLAGS_LE_ONLY_GENERAL_DISC_MODE);
  Bluefruit.Advertising.addTxPower();
  Bluefruit.Advertising.addAppearance(BLE_APPEARANCE_HID_MOUSE);
  
  // Include BLE HID service
  Bluefruit.Advertising.addService(blehid);

  // There is enough room for 'Name' in the advertising packet
  Bluefruit.Advertising.addName();
  
  /* Start Advertising
   * - Enable auto advertising if disconnected
   * - Interval:  fast mode = 20 ms, slow mode = 152.5 ms
   * - Timeout for fast mode is 30 seconds
   * - Start(timeout) with timeout = 0 will advertise forever (until connected)
   * 
   * For recommended advertising interval
   * https://developer.apple.com/library/content/qa/qa1931/_index.html   
   */
  Bluefruit.Advertising.restartOnDisconnect(true);
  Bluefruit.Advertising.setInterval(32, 244);    // in unit of 0.625 ms
  Bluefruit.Advertising.setFastTimeout(30);      // number of seconds in fast mode
  Bluefruit.Advertising.start(0);                // 0 = Don't stop advertising after n seconds  
}

void loop() 
{    
  if (Serial.available())
  {
    char ch = (char) Serial.read();

    // convert to upper case
    ch = (char) toupper(ch);
    
    // echo
    Serial.println(ch);
  
    switch(ch)
    {
      // WASD to move the mouse
      case 'W':
        blehid.mouseMove(0, -MOVE_STEP);
      break;

      case 'A':
        blehid.mouseMove(-MOVE_STEP, 0);
      break;

      case 'S':
        blehid.mouseMove(0, MOVE_STEP);
      break;

      case 'D':
        blehid.mouseMove(MOVE_STEP, 0);
      break;

      // LRMBF for mouse button(s)
      case 'L':
        blehid.mouseButtonPress(MOUSE_BUTTON_LEFT);
      break;

      case 'R':
        blehid.mouseButtonPress(MOUSE_BUTTON_RIGHT);
      break;

      case 'M':
        blehid.mouseButtonPress(MOUSE_BUTTON_MIDDLE);
      break;

      case 'B':
        blehid.mouseButtonPress(MOUSE_BUTTON_BACKWARD);
      break;

      case 'F':
        // This key is not always supported by every OS
        blehid.mouseButtonPress(MOUSE_BUTTON_FORWARD);
      break;

      case 'X':
        // X to release all buttons
        blehid.mouseButtonRelease();
      break;

      case '['
        blehid.keyPress(0x01);
        blehid.mouseScroll(-1);
        blehid.mouseScroll(0);
        blehid.keyRelease();
      break;

      case ']'
        blehid.keyPress(0x01);
        blehid.mouseScroll(1);
        blehid.mouseScroll(0);
        blehid.keyRelease();
      break;

      default: break;
    }
  }
}

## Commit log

2025-02-17 Create MouseMovement.ino
    I combined and edited the example codes such that the gyroscope can now control mouse movements. This still needs to be tested and refined. -David
2025-03-03 Create Event_test.ino
    Our trigger event code, currently testing zoom.
2025-03-17 Update readme to include info on how to install and use the Arduino IDE
2025-04-16 combined buttons with new gesture code
2025-04-28 Add 3d print stl artifacts
    [Backhand.stl, Laser pointer cover.stl, arduino guard.stl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]
